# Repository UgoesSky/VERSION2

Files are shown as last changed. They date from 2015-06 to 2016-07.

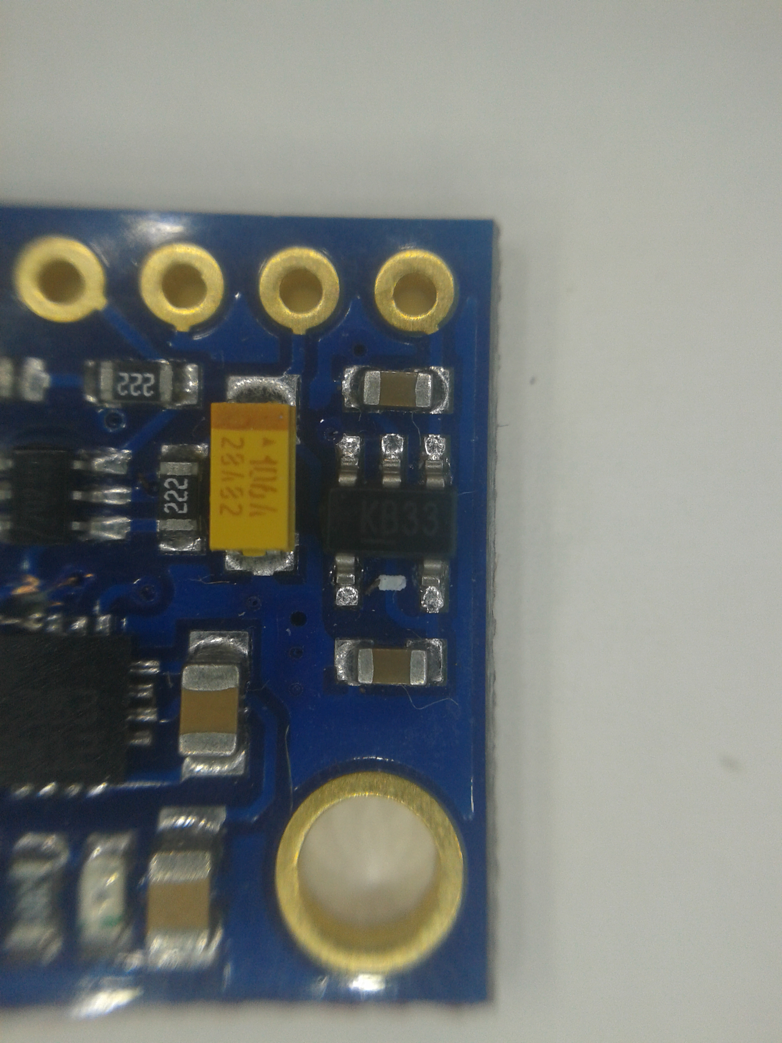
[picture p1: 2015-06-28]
Hardware/GY80/GY88_top1.jpg

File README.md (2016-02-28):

# What we are doing here?
We develop an balloon for the Stratosphere. We are a small group of students from a bording school in southern Germany, near Ulm. In 2014 we had the idea to develop and launch an balloon into the Stratosphere. Our first balloon launched on 20 March 2015 during the partial solar eclipse in Europe. At almost 22 km, our balloon, filled with helium, burst. The capsule landed save, hanging on a parachute.

Now we are developing our second balloon. We target this launch in Summer 2016.
# VERSION2
Die Daten für V2 des Ballonprojekts 'UgoesSky'.

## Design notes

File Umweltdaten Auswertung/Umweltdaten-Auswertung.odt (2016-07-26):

UgoesSky V2

Umweltdaten Auswertung

# Dateien

aprs_roh_v2.txt | APRS Rohdaten von aprs.fi
aprs.txt | APRS Daten unvollstäbdige Datensätze entfernt
aprs-zeit.txt | APRS Zeitstempel cat aprs.txt |grep -o 2016-07-17......... > aprs-zeit.txt
aprs-hoehe.txt | APRS Höhe in Fuß cat aprs.txt |grep -o A=...... > aprs-hoehe.txt
Umweltdaten.txt | Rohdaten Umwelt
Umweltdaten-Tabelle.ods | Tabelle und Diagramme

## Umweltdaten.ods

### Rohdaten

A | Zeit (MESZ) | Zeitstempel (kann etwas abweichen)
B | Temperatur Innen BMP085 (in °C) | Innentemperatur BMP085 | Genauigkeit: typ. ±1,0°C Auflösung: 0,1°C
C | Temperatur Außen seitlich DHT22 (in °C) | Außentemperatur seitlich DHT22 | Genauigkeit: typ. ±0,5°C Auflösung: 0,1°C
D | Temperatur Innen TMP75 (in °C) | Innentemperatur TMP75 | Genauigkeit: typ. ±0,5°C Auflösung: 0,0625°C
E | Temperatur Außen Unten TMP75 (in °C) | Außentemperatur unten TMP75
F | Temperatur Außen Oben TMP75 (in °C) | Außentemperatur oben TMP75 | Genauigkeit: typ. ±1,0°C Auflösung: 0,0625°C
G | Temperatur Innen TMP75 (in °C) roh | Rohwerte negative Werte falsch | =WENN(G3>100;G3-256;G3)
H | Temperatur Außen Unten TMP75 (in °C) roh
I | Temperatur Außen Oben TMP75 (in °C) roh
J | Absolute Luftfeuchte (in g/kg) | Berechnet aus relativer Luftfeuchte, Temperatur und Druck | =0,622*K3/100*L3/(M3-K3/100*L3)*1000
K | Relative Luftfeuchte (in %) | Relative Luftfeuchte seitlich DHT22 | Genauigkeit: typ. ±2% Auflösung: 0,1%
L | Wasserdampfpartialdurck (in Pa) | Nötig für Berechnung der absoluten Luftfeuchte | =WENN(C3<=0;4,689*(1,486+C3/100)^12,3;WENN(C3>0;288,68*(1,098+C3/100)^8,02;""))
M | Druck (in Pa) | Druck innen BMP085 | Genauigkeit: ±400Pa Auflösung: 1Pa
N | Standardatmosphäre | Druck / 101325 | Auflösung: 0,0001
O | Höhe (in m) | Aus Druck berechnete Höhe | Auflösung: 0,01m
P | Spannung (ADC-Wert) | Rohwert zwischen 0...1023 | ausgefallen
Q | Zähler | Zählervaiabler, Bereich 1...60 Bei Überlauf wird gespeichert

### APRS Höhe

A | Zeit (MESZ)
B | APRS Höhe (Meter) | =C2*0,3048
C | APRS Höhe (Fuß)

### Rohdiagramm

Diagramm mit allen Werten zum kopieren

### Temperatur

Temperaturkurven

### Temperatur Höhe

Temperaturkurven mit Höhe

### Höhe – APRS Höhe

Vergleich zwischen den Werten. Leichter Zeitoffset möglich.

### Druck Höhe

### Temperatur Luftfeuchte

Temperatur und Luftfeuchte

### Höhe Luftfeuchte

Höhe und Luftfeuchte

### Spannung Höhe

### Spannung Temperatur

# Interpretation

## Temperatur

Vor dem Start steigt die Außentemperatur oben durch Sonnenstrahlung an. Die Außentemperatur seitlich steigt nur leicht und die Außentemperatur unten wird nicht beeinflusst.

Am Anfang erwärmt sich die Box innen, die Wärme wird aber wieder nach außen abgegeben.

Ab etwa 12 km Höhe ist der Luftdruck zu gering, dass kaum mehr Wärme nach außen abgegeben werden kann (Vakuumisolation). Deshalb steigt die Außentemperatur am Styropor stark an. Nach einiger Zeit fängt auch die Innentemperatur an zu steigen.

Die Unterschiede zwischen den einzelnen Sensoren lassen sich durch die Erwärmung des Styropors und der Sonneneinstrahlung erklären. Die Erwärmung des Styropos ist von der Dicke und der Wärmeverteilung in der Box abhängig.

Der untere Sensor wird durch die Styroporschicht von 3cm und das direkt an das Styropor gekoppelte Funkgerät am stärkstem erwärmt.

Der obere Sensor wird vermutlich hauptsächlich durch Sonneneinstrahlung erwärmt, da hier das Styropor 6cm dick ist.

Der seitliche Sensor wird am wenigsten erwärmt, da hier weder eine Wärmequelle im Innern sitzt, noch die Sonneneinstrahlung so stark ist. Zudem ist der Sensor im Gegensatz zu den anderen Weiß statt schwarz.

## Luftfeuchte

In der relativen Luftfechte ist gut zu erkennen, dass der Ballon bei etwa 2,5 km die Wolken durchfliegt.

Außerdem gibt es noch Schwankungen zwischen 4km und 8km für die sich noch keine Erklärung gefunden hat.

Bis 16km sinkt die relative Luftfeuchte, bis sie bei 16km den Minimalwert erreicht hat.

## Ausfall

Das System ist um etwa 16:25 nach 1:40h Flugzeit und einer Laufzeit von gut 2h ausgefallen.

Es fallen keine Auffälligkeiten in den gemessene Werten auf. Nur die Akkuspannung wurde ab dem Start nicht mehr korrekt gemessen.

Weshalb das System ausgefallen ist, ist noch nicht geklärt.

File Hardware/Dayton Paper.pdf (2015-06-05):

## Proposal for SSTV Mode Specifications

JL Barber (N7CXI), Silicon Pixels Presented at the Dayton SSTV forum, 20 May 2000

Forward
When I first began investigating the requirements for designing an SSTV system, one of the first obstacles I ran into was the lack of accurate information on the exact format and timings of the many SSTV modes in use. All the information I found was either generalized, or based on the results of reverse engineering existing systems. As so often noted, this has resulted in many compatibility problems over the years. This paper is a beginning at changing that. The reason I call it a beginning is that other developers may not agree that the specifications presented here should become standards. Even so, every venture must start somewhere. If the developer’s community at large can agree on reasonable standards, we’ll be happy to adopt them. In the meantime, we present these proposed specifications for use or publication by anyone who finds them useful.

Data sources
The specifications presented in this paper include only those that we have “hard” data for. In the case of Scottie, Martin, Robot, and Wrasse modes, our source is the firmware for the Robot 1200C. For other modes:
Pasokon “P” modes | John Langner | (author)
“PD” modes | Don Rotier | (author)
FAX480 | Dr. Ralph Taggart (author)
Note: | Those familiar with our ChromaPIX and W95SSTV systems will note the absence of specifications for the AVT
modes. Since we have no solid data on AVT from the author, we have not included them here.
Numeric precision
The timings specified here are generally given in milliseconds, (ms) except where other units work better for examples. Scan times have been rounded to .001ms, which is adequate precision for any known application. Total transmission times are not calculated precisely, since the exact lengths aren’t relevant for development purposes. In the case of the Robot firmware, we can provide the 8031 clock frequency and “counts”, if absolute precision is desired.

Disclaimer
While every attempt has been made to ensure the accuracy of this information, we can’t absolutely guarantee it to be completely without error.

Layout
Rather than present mode timings with pictures, we’ve chosen to “step through” each mode, in sequence. We believe this method will be more useful to developers, as it reveals the sequence of events more readily than an image.

VIS Code and Robot calibration header
All standard SSTV modes utilize a unique digital code that identifies the mode to a receiving system. The code is called the VIS, or Vertical Interval Signal code. Although the entire calibration header is often referred to as the “VIS code”, the code itself is only a part of it. The seven-bit code is transmitted least-significant-bit (LSB) first, and uses “even” parity.

Calibration header with VIS code

TIME(ms) | FREQUENCY(hz) | IDENTITY
300 | 1900 | Leader tone
10 | 1200 | break
300 | 1900 | Leader tone
30 | 1200 | VIS start bit
30 | bit 0 | 1100hz = “1”, 1300hz = “0”
30 | bit 1 | “”
30 | bit 2 | “”
30 | bit 3 | “”
30 | bit 4 | “”
30 | bit 5 | “”
30 | bit 6 | “”
30 | PARITY | Even=1300hz, Odd=1100hz
30 | 1200 | VIS stop bit

Note that all mode specifications begin immediately after the VIS stop bit.

SCOTTIE MODES
“Scottie” modes, although the most commonly used modes in the US, are unusual for two reasons. The combination of the two has caused considerable confusion over the years:
- The first scan line (only) begins with an out-of-sequence 9.0ms “starting” sync pulse, at 1200hz.
- The “regular” sync pulse is positioned between the Blue and Red scans, rather than at the line break, as with other modes.

VIS CODES
Scottie 1 | 60d (decimal)
Scottie 2 | 56d
Scottie DX 76d
COLOR MODE | RGB (1500-2300hz luminance range)
SCAN SEQUENCE | Green, Blue, Red
NUMBER OF LINES | 256
NORMAL DISPLAY RES 320x256 (including 16-line header)

TRANSMISSION TIME
Scottie 1 | 109.6 seconds (not including cal. header/VIS)
Scottie 2 | 71.1 seconds
Scottie DX | 268.9 seconds

COLOR SCAN TIME
Scottie 1 | 138.240ms (.4320ms/pixel @ 320 pixels/line)
Scottie 2 | 88.064ms (.2752ms/pixel @ 320 pixels/line)
Scottie DX 345.6ms | (1.0800ms/pixel @ 320 pixels/line)

TIMING SEQUENCE
(1) “Starting” sync pulse (first line only!) | 9.0ms | 1200hz
(2) Separator pulse | 1.5ms | 1500hz
(3) Green scan
(4) Separator pulse | 1.5ms | 1500hz
(5) Blue scan
(6) Sync pulse | 9.0ms | 1200hz
(7) Sync porch | 1.5ms | 1500hz
(8) Red scan

After the first line, repeat steps 2 – 8 for all following lines.

MARTIN MODES
Martin modes are straightforward, with the sync pulse occurring at line breaks.

VIS CODES
Martin 1 | 44d (decimal)
Martin 2 | 40d
COLOR MODE | RGB (1500-2300hz luminance range)
SCAN SEQUENCE | Green, Blue, Red
NUMBER OF LINES | 256
NORMAL DISPLAY RES 320x256 (including 16-line header)

TRANSMISSION TIME
Martin 1 | 114.3 seconds (not including cal. header/VIS)
Martin 2 | 58.06 seconds

COLOR SCAN TIME
Martin 1 | 146.432ms (.4576ms/pixel @ 320 pixels/line)
Martin 2 | 73.216ms (.2288ms/pixel @ 320 pixels/line)

TIMING SEQUENCE
(1) Sync pulse | 4.862ms | 1200hz
(2) Sync porch | 0.572ms | 1500hz
(3) Green scan
(4) Separator pulse | 0.572ms | 1500hz
(5) Blue scan
(6) Separator pulse | 0.572ms | 1500hz
(7) Red scan
(8) Separator pulse | 0.572ms | 1500hz

Repeat the above sequence for 256 lines.

ROBOT 36 COLOR
Robot 36 is probably the most complex of all SSTV modes:
- It uses Y, R-Y, B-Y color encoding
- The R-Y color information is averaged for two lines, and transmitted on even lines.
- The B-Y color information is averaged for two lines, and transmitted on odd lines.
- The R-Y and B-Y scans have only ½ the period (44ms) of the Y scan. (88ms)
- Even lines use a 1500hz “separator” pulse, while odd lines use 2300hz.

VIS CODE 8d (decimal)

COLOR MODE | Y, R-Y, B-Y (see Appendix B)
SCAN SEQUENCE | Y, R-Y (even lines) Y, B-Y (odd lines)
NUMBER OF LINES | 240
TRANSMISSION TIME | 36 seconds (not including cal. header/VIS)

Note: For clarity, 2 complete lines are shown below

TIMING SEQUENCE
(1) Sync pulse | 9.0ms | 1200hz
(2) Sync porch | 3.0ms | 1500hz
(3) Y scan | 88.0ms
(4) “Even” separator pulse | 4.5ms | 1500hz
(5) Porch | 1.5ms | 1900hz
(6) R-Y scan | 44ms
(7) Sync pulse | 9.0ms | 1200hz
(8) Sync porch | 3.0ms | 1500hz
(9) Y scan | 88.0ms
(10) “Odd” separator pulse | 4.5ms | 2300hz
(11) Porch | 1.5ms | 1900hz
(12) B-Y scan | 44ms

Repeat the sequence above for 240 lines.

ROBOT 72 COLOR
Robot 72 is somewhat simpler than Robot 36, but still suffers from different scan periods for the Y versus the R-Y and B-Y scans.

VIS CODE 12d (decimal)

COLOR MODE | Y, R-Y, B-Y (see Appendix B)
SCAN SEQUENCE | Y, R-Y, B-Y
NUMBER OF LINES | 240
TRANSMISSION TIME | 72 seconds (not including cal. header/VIS)
TIMING SEQUENCE | (one line shown)
(1) Sync pulse | 9.0ms | 1200hz
(2) Sync porch | 3.0ms | 1500hz
(3) Y scan | 138ms
(4) Separator pulse | 4.5ms | 1500hz
(5) Porch | 1.5ms | 1900hz
(6) R-Y scan | 69ms
(7) Separator pulse | 4.5ms | 2300hz
(8) Porch | 1.5ms | 1500hz
(9) B-Y scan | 69ms

Repeat the above sequence for 240 lines.

WRASSE SC2-180
SC2-180 is probably the simplest RGB SSTV mode.

VIS CODE 55d (decimal)

COLOR MODE | RGB (1500-2300hz luminance range)
SCAN SEQUENCE | Red, Green, Blue
NUMBER OF LINES | 256
TRANSMISSION TIME | 182 seconds (not including cal. header/VIS)
COLOR SCAN TIME | 235.000ms (.7344ms/pixel @ 320 pixels/line)
TIMING SEQUENCE | (one line shown)
(1) Sync pulse | 5.5225ms | 1200hz
(2) Porch | 0.500ms | 1500hz
(3) Red scan
(4) Green scan
(5) Blue scan

Repeat the above sequence for 256 lines.

PASOKON “P” modes
The “P” modes are all designed to display at 640x496, including a 16-line header. They differ somewhat from other “families” of modes, in that the sync pulse and porch periods vary with the sub-mode. When John Langner originally authored them, his intent was that the pixel clock, sync, and porch periods all be evenly divisible into a standard RS232 clock rate.

VIS CODES:
P3 | 113d (decimal)
P5 | 114d
P7 | 115d
COLOR MODE | RGB (1500-2300hz luminance range)
SCAN SEQUENCE | Red, Green, Blue
NUMBER OF LINES | 496

TRANSMISSION TIMES
P3 | 203 seconds (not including cal. header/VIS)
P5 | 304.6 seconds
P7 | 406.1 seconds

COLOR SCAN TIMES:
P3 | 133.333ms (.2083ms/pixel @ 640 pixels/line)
P5 | 200.000ms (.3125ms/pixel @ 640 pixels/line)
P7 | 266.666ms (.4167ms/pixel @ 640 pixels/line)

SYNC PERIODS
P3 | 5.208ms | 1200hz
P5 | 7.813ms | 1200hz
P7 | 10.417ms | 1200hz

PORCH PERIODS
P3 | 1.042ms | 1500hz
P5 | 1.563ms | 1500hz
P7 | 2.083ms | 1500hz
TIMING SEQUENCE | (one line shown)
(1) Sync pulse
(2) Porch
(3) Red scan
(4) Porch
(5) Green scan
(6) Porch
(7) Blue scan
(8) Porch
| Repeat the above sequence for 496 lines.

PD Modes
The PD modes were developed jointly by Don Rotier and Paul Turner. Although they’re a little complicated, they represent a fair trade-off between color accuracy and transmission time.

VIS CODES
PD50 | 93d (decimal)
PD90 | 99d
PD120 | 95d
PD160 | 98d
PD180 | 96d
PD240 | 97d
PD290 | 94d
COLOR MODE | Y, R-Y, B-Y (See Appendix B)
SCAN SEQUENCE | Y, R-Y, B-Y

NORMAL DISPLAY RESOLUTION
PD50 | 320x256 | (all include 16-line header)
PD90 | 320x256
PD120 | 640x496
PD160 | 512x400
PD180 | 640x496
PD240 | 640x496
PD290 | 800x616

TRANSMISSION TIMES
PD50 | | 49.7 seconds
PD90 | | 90.0 seconds
PD120 | | 126.1 seconds
PD160 | | 160.9 seconds
PD180 | | 187.1 seconds
PD240 | | 248.0 seconds
PD290 | | 288.7 seconds

COLOR SCAN TIMES (Y, R-Y, B-Y)
PD50 | | 91.520ms
PD90 | | 170.240ms
PD120 | | 121.600ms
PD160 | | 195.584ms
PD180 | | 183.040ms
PD240 | | 244.480ms
PD290 | | 228.800ms

TIMING SEQUENCE
Note: two complete lines are shown.
(1) Sync pulse | 20.000 | 1200hz
(2) Porch | 2.080ms | 1500hz
(3) Y scan (from odd line)
(4) R-Y scan averaged for two lines
(5) B-Y averaged for two lines
(6) Y scan (from even line)

Repeat until correct number of lines are transmitted for sub-mode.

FAX480 mode

FAX480 is a monochrome FAX, rather than a “true” SSTV mode. It uses a 5-second FAX tone “header” followed by a phasing area, instead of a Robot calibration header and VIS code. It was developed by Dr. Ralph Taggart, WB8DQT

We’ve included it here because it’s useful for monochrome image transmission, and is often included with SSTV software. (ChromaPIX included)

COLOR MODE | Monochrome (1500-2300hz luminance range)
NORMAL DISPLAY RES 512x480
NUMBER OF LINES | 480
SCAN TIME | .512ms x 512 pixels = 262.144ms

HEADER (start tone)
(1) | 2.05ms | 2300hz
(2) | 2.05ms | 1500hz

Repeat this sequence 1220 times, for a total of 5.002 seconds.

PHASING INTERVAL (20 lines)
(1) | Sync | 5.12ms | 1200hz
(2) | White | .512ms x 512 pixels = 262.144ms

Repeat this sequence 20 times, for a total of 20 lines.

TIMING SEQUENCE
(1) Header
(2) Phasing interval
(3) Sync | | 5.12ms | 1200hz
(4) Scan line

Repeat 3-4 until 480 lines have been transmitted.

Note: Some systems (ChromaPIX included) use the 20-line phasing area for video.)

Appendix A | RGB Color Encoding

Of the two encoding methods used in SSTV, RGB is by far the simplest. The calculations below are intended for use with non-linear 24-bit RGB color, which is standard for modern computer-based systems.

24-bit RGB is straightforward. 8-bit (0-255) Red, Green, and Blue values are “packed” into a single 24-bit identity. Red values occupy the lowest 8 bits, followed by Green, then Blue. This allows for a maximum of 16,777,216 unique combinations of colors, which is generally adequate for any but the highest-end imaging systems.

To extract individual 8-bit R,G,B values from a 24-bit RGB encoded pixel :

RedByte | = colorval AND 255
GreenByte | = (colorval AND 65280) / 256
BlueByte | = (colorval AND 16711680) / 65536

If your programming language and platform supports it, shifting and masking the 24-bit value may be slightly faster than using the “generic” method above, since it would avoid the division.

SSTV systems use the frequency range of 1500-2300hz to represent the range of brightness values from pure black to pure white. Because of this, we must convert our 8-bit R,G,B values into the appropriate frequency:

Frequency = 1500 + (ColorByte * 3.1372549)

Conversely, to derive the 8-bit R,G, or B value from a frequency:

ColorByte = (Frequency – 1500 ) / 3.1372549

Obviously, look-up tables could be calculated in advance, avoiding the necessity of performing floating-point multiplies and divisions for encoding and decoding every pixel in every scan.

For receiving purposes, the easiest way to recombine the individual R,G, and B values back into a 24-bit RGB identity is to use the RGB(n,n,n) macro provided with most modern compilers. If that isn’t possible :

RedVal | = ColorByte (directly, no conversion required)
GreenVal | = ColorByte * 256
BlueVal | = ColorByte * 65536

Once the R, G, and B values have been scaled correctly, they can be simply added together to form the 24-bit identity:

ColorVal = Red + Green + Blue

Appendix B | Y, R-Y, B-Y Color Encoding

(Y, R-Y, B-Y) encoding is used in Robot and PD modes, as well as the seldom-used Wrasse SC2-120 mode. This method of encoding is also referred to as (Y/C), (Y’U’V’), (Y’CBCR), and other names. Although all these refer to the same overall method of encoding, the exact scalings used vary somewhat by implementation and developer.

The encoding used in ChromaPIX and W95SSTV is compliant with
ITU BT. Rec. 601. (the 1953 NTSC standard) Because there has been no clearly-defined standard, the scalings described below may vary slightly from those used by other developers.

To convert non-linear RGB to [Y, R-Y, B-Y] (scaled 0-255) :

Y = 16.0 + (.003906 * ((65.738 * R) + (129.057 * G) + (25.064 * B)))

RY = 128.0 + (.003906 * ((112.439 * R) + (-94.154 * G) + (-18.285 * B)))

BY = 128.0 + (.003906 * ((-37.945 * R) + (-74.494 * G) + (112.439 * B)))

Again, as with RGB encoding, these values can be converted to frequency, for SSTV transmission :

Frequency = 1500 + (v * 3.1372549)
(where ‘v’ is the Y, R-Y, or B-Y value)

Conversely, Y, R-Y, B-Y values scaled 0-255 may be converted back to non-linear RGB:

R = 0.003906 * ((298.082 * (Y – 16.0)) + (408.583 * (RY – 128.0)))

G = 0.003906 * ((298.082 * (Y – 16.0)) + (-100.291 * (BY – 128.0)) + (-208.12 * (RY – 128.0)))

B = 0.003906 * ((298.082 * (Y – 16.0)) + (516.411 * (BY – 128.0)))

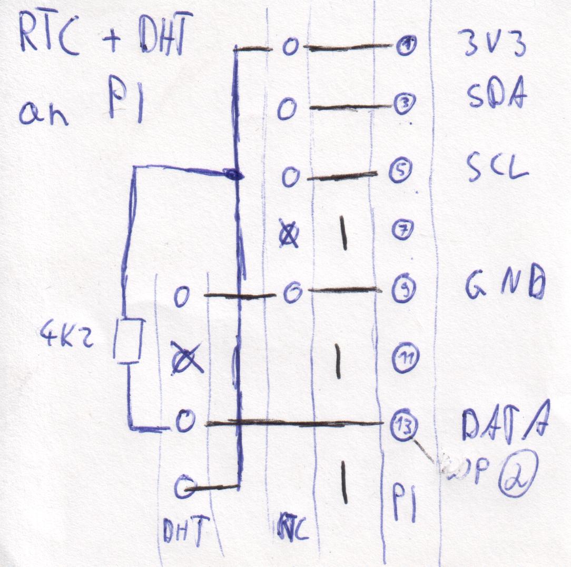
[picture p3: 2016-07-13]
Hardware/RTC-DHT-PI.jpg

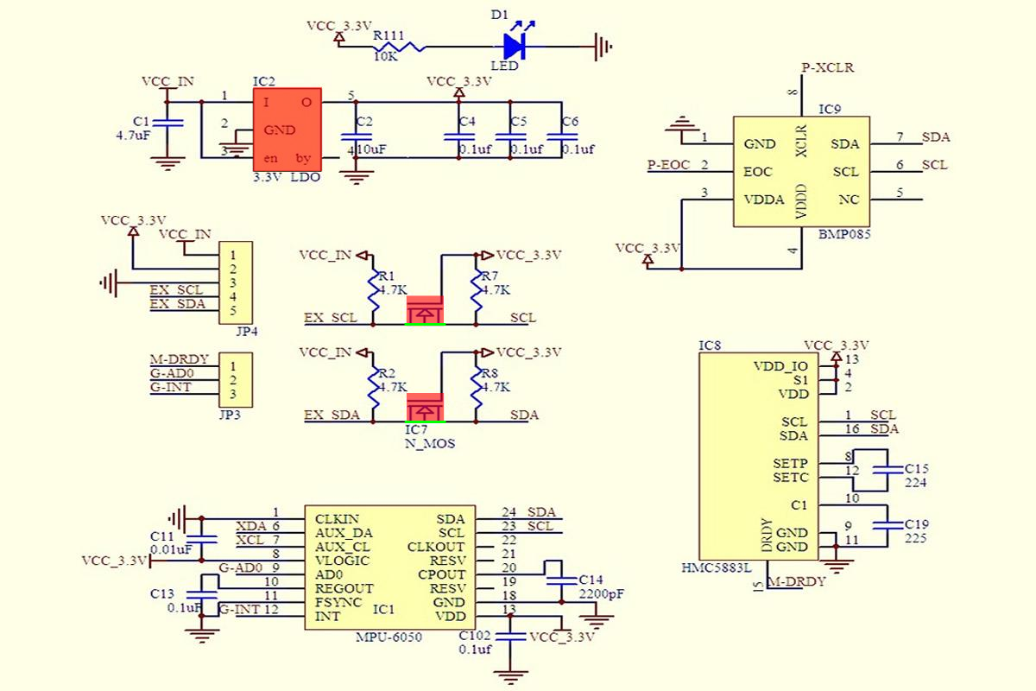
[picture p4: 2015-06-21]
Hardware/GY80/GY88_3.3v_SCHALTPLAN.png

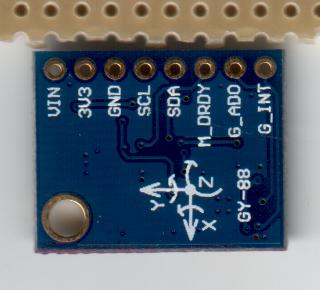
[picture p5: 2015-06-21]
Hardware/GY80/GY88_bottum.jpg

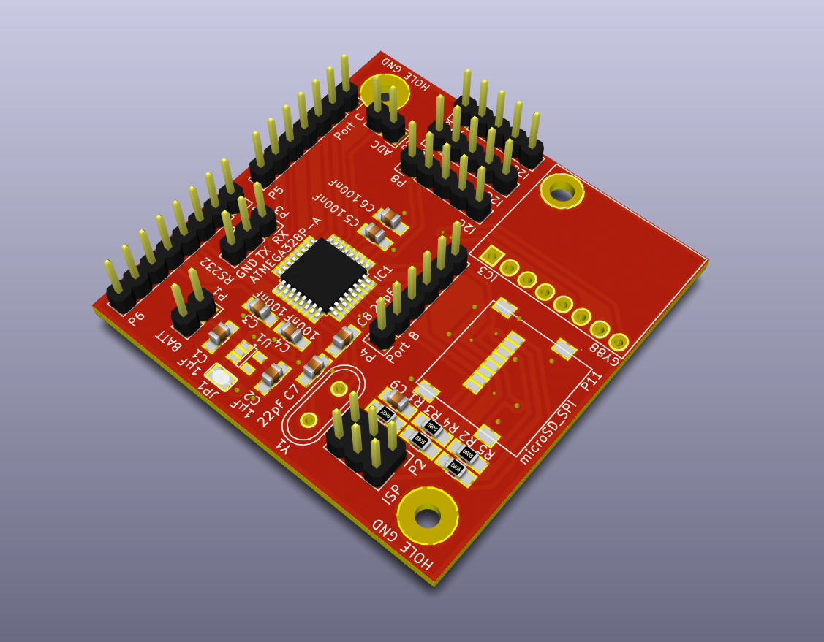
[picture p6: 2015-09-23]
Hardware/Umweltdaten/Bilder/top_3d.png

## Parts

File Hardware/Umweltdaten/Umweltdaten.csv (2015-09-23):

Reference | Value | Footprint | Datasheet
C1 | 1µF | Capacitors_SMD:C_0805_HandSoldering
P1 | BATT | Pin_Headers:Pin_Header_Straight_1x02
U1 | TLV70233DBV | Housings_SOT-23_SOT-143_TSOT-6:SOT-23-5
JP1 | Ureg EN | Footprints:SJ
C2 | 1µF | Capacitors_SMD:C_0805_HandSoldering
R5 | 10k | Resistors_SMD:R_0805_HandSoldering
R4 | 10k | Resistors_SMD:R_0805_HandSoldering
R3 | 10k | Resistors_SMD:R_0805_HandSoldering
R2 | 10k | Resistors_SMD:R_0805_HandSoldering
P11 | microSD_SPI | Footprints:microSD
IC3 | GY88 | Footprints:GY88
JP2 | G_AD0 | Footprints:SJ_2
IC1 | ATMEGA328P-A | Housings_QFP:TQFP-32_7x7mm_Pitch0.8mm
C4 | 100nF | Capacitors_SMD:C_0805_HandSoldering
C5 | 100nF | Capacitors_SMD:C_0805_HandSoldering
C3 | 100nF | Capacitors_SMD:C_0805_HandSoldering
Y1 | Crystal 16Mhz | Crystals:Crystal_HC49-U_Vertical
C7 | 22pF | Capacitors_SMD:C_0805_HandSoldering
C8 | 22pF | Capacitors_SMD:C_0805_HandSoldering
C9 | 100nF | Capacitors_SMD:C_0805_HandSoldering
R1 | 10k | Resistors_SMD:R_0805_HandSoldering
C6 | 100nF | Capacitors_SMD:C_0805_HandSoldering
P3 | RS232 | Pin_Headers:Pin_Header_Straight_1x03
P2 | ISP | Pin_Headers:Pin_Header_Straight_2x03
P5 | Port C | Pin_Headers:Pin_Header_Straight_1x07
P6 | Port D | Pin_Headers:Pin_Header_Straight_1x08
P7 | ADC | Pin_Headers:Pin_Header_Straight_1x02
P8 | I2C | Pin_Headers:Pin_Header_Straight_1x05
P9 | I2C | Pin_Headers:Pin_Header_Straight_1x05
P10 | I2C | Pin_Headers:Pin_Header_Straight_1x05
P4 | Port B | Pin_Headers:Pin_Header_Straight_1x06

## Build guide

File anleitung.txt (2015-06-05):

1. Dateien verändern
2. Im richtigen Branch?
	git checkout master
		     sstv
3. Veränderte Dateien in staging packen
entweder
	git add <DATEINAME> 	für einzelne Datei
oder
	git add .		für alle Veränderungen
3. Commit erstellen
	git commit -m "BESCHREIBUNG"
Nun befindet sich die aktuelle Version im lokalen Repository.
4. Änderung auf den Server schicken
	git push <origin BRANCHNAME>
wenn Fehlermeldung, Repo aktualisieren
	git pull <origin BRANCHNAME>
5. Weiter bei Schritt 1

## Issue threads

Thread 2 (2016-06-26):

Umweldaten Platine

jstjst, 2016-06-26:
- [ ] microSD card footprint wrong
- [ ] microSD card wrong oriantation
- [ ] Batt connector no polarity marking
- [ ] I2C pullups
- [ ] TMP75 O.S. not connected
- [ ] ISP connector no polarity makring
- [ ] TLV70233 NC pin
- [ ] GY88 G_AD0 pin connected to GND

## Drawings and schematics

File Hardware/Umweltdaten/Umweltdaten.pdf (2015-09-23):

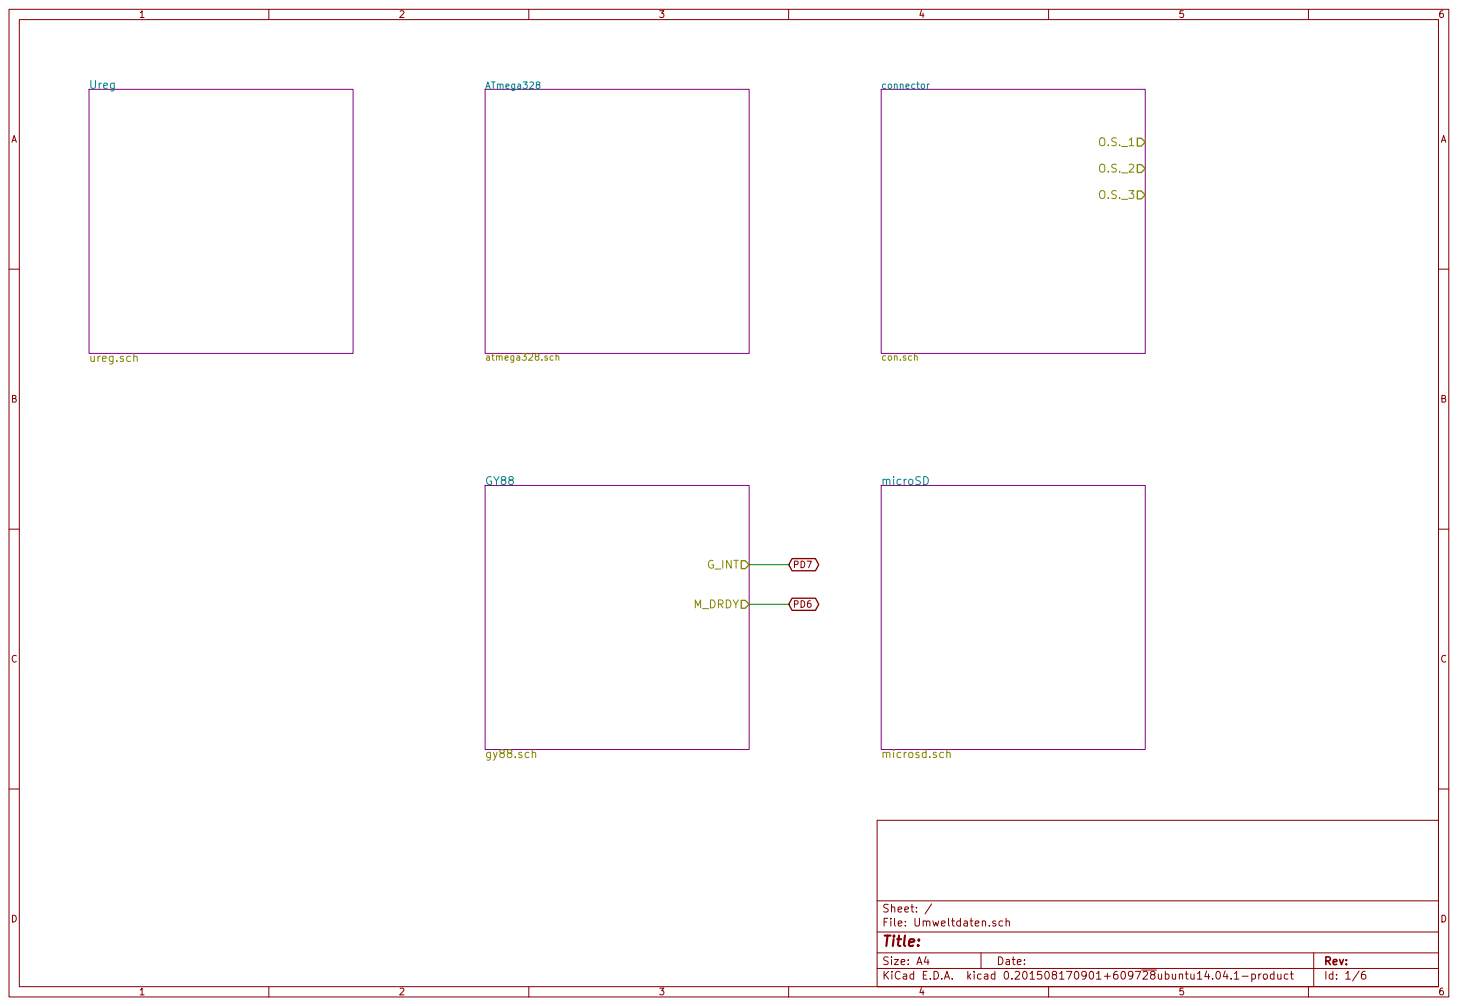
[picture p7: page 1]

Id: 1/6 Title: File: Umweltdaten.sch Sheet: /

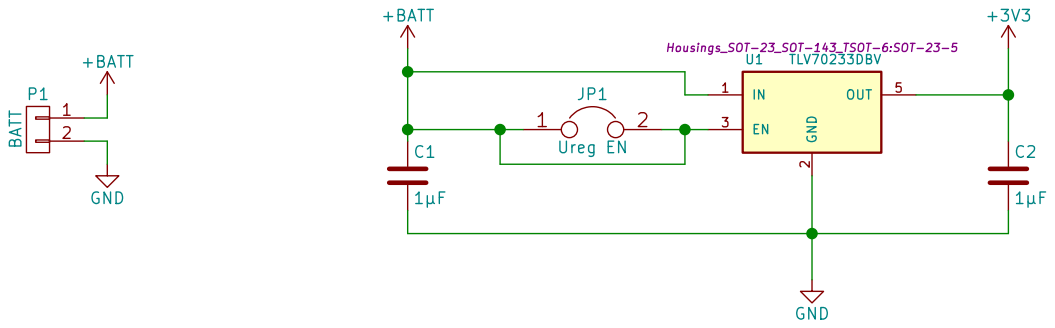
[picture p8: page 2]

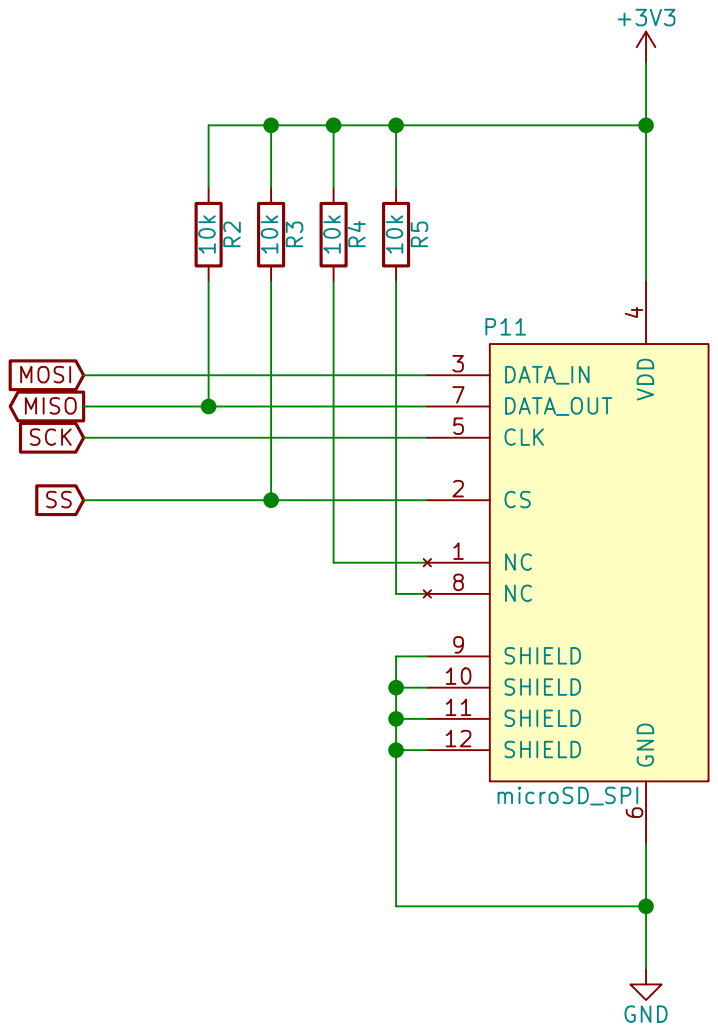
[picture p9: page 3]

6 DATA_OUT 7 NC 8 SHIELD 9 SHIELD 10 SHIELD 11 SHIELD 12 P11microSD_SPI

Id: 3/6 Title: File: microsd.sch Sheet: /microSD/

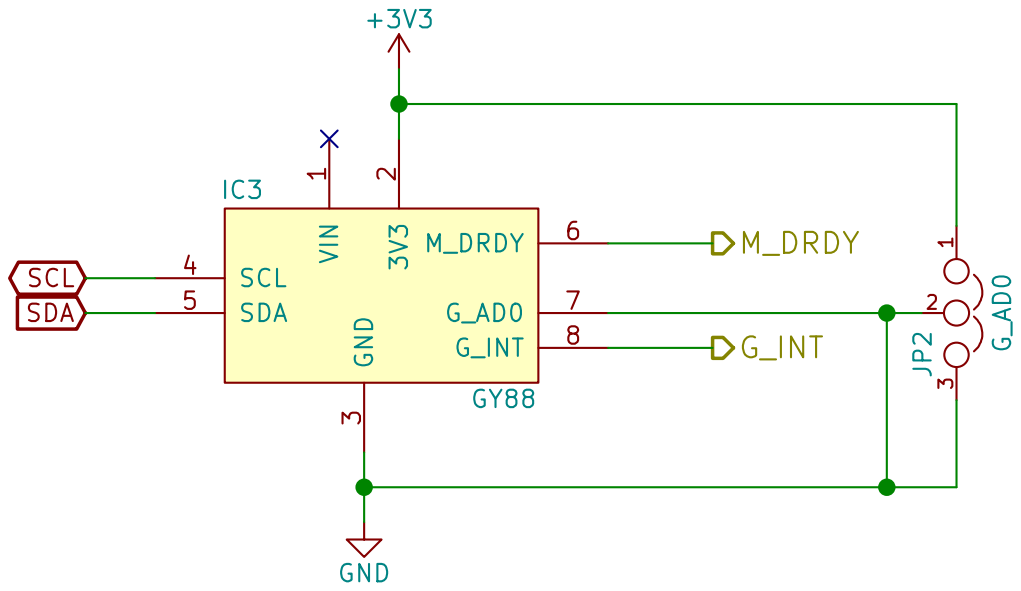
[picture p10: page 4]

File: gy88.sch Sheet: /GY88/ VIN

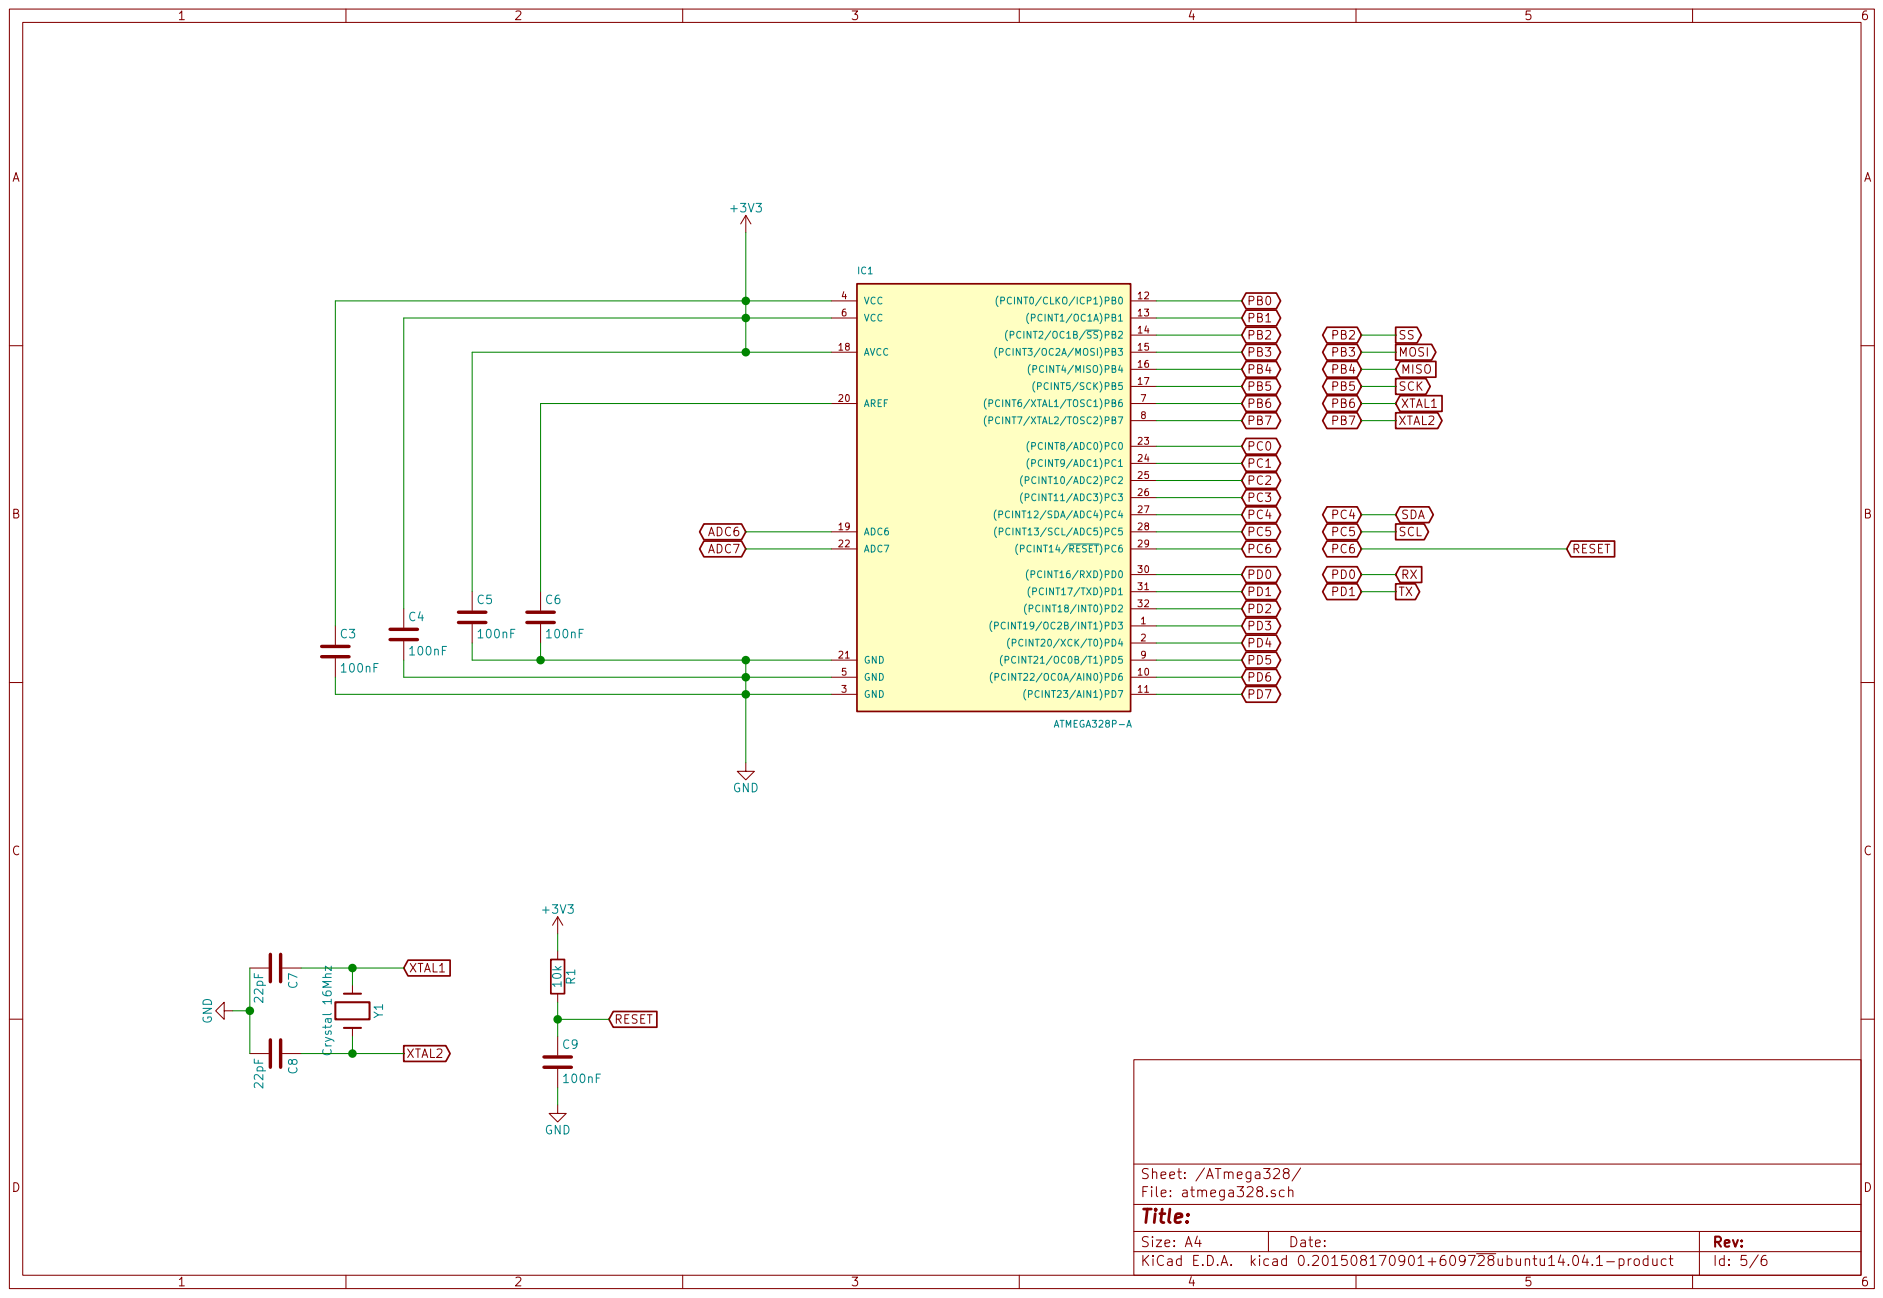
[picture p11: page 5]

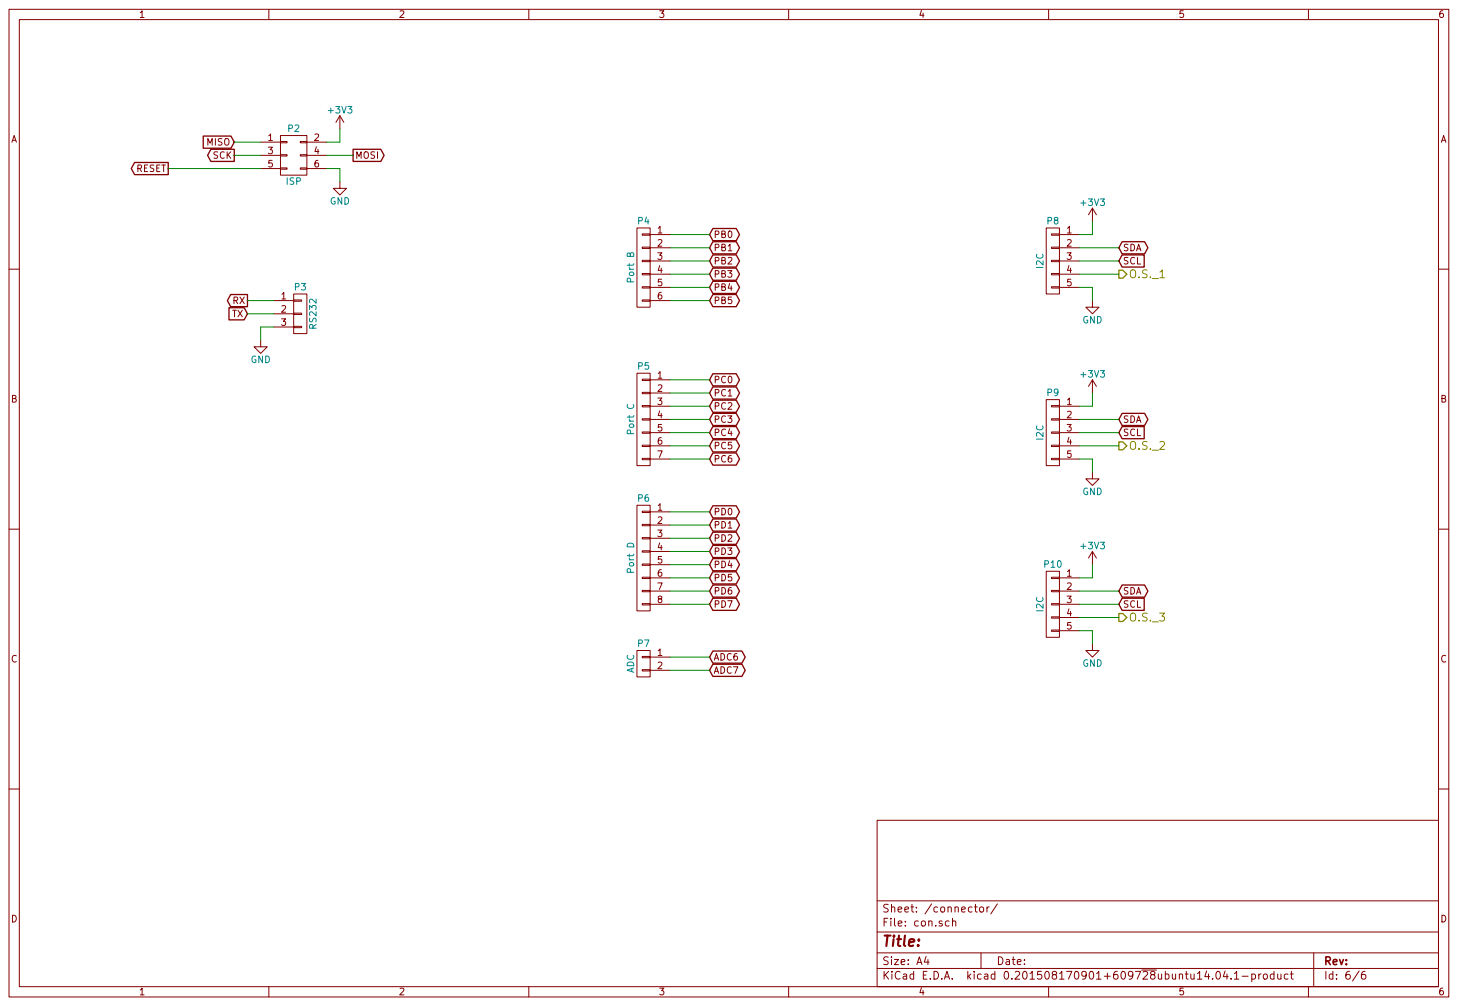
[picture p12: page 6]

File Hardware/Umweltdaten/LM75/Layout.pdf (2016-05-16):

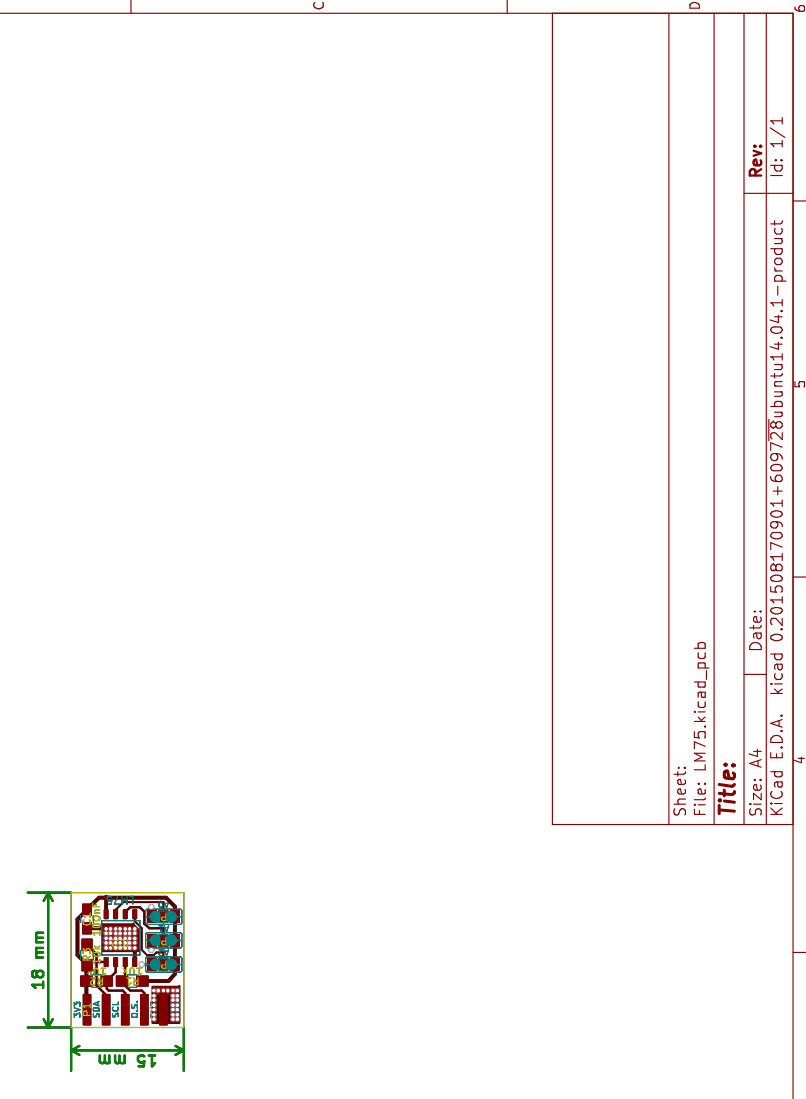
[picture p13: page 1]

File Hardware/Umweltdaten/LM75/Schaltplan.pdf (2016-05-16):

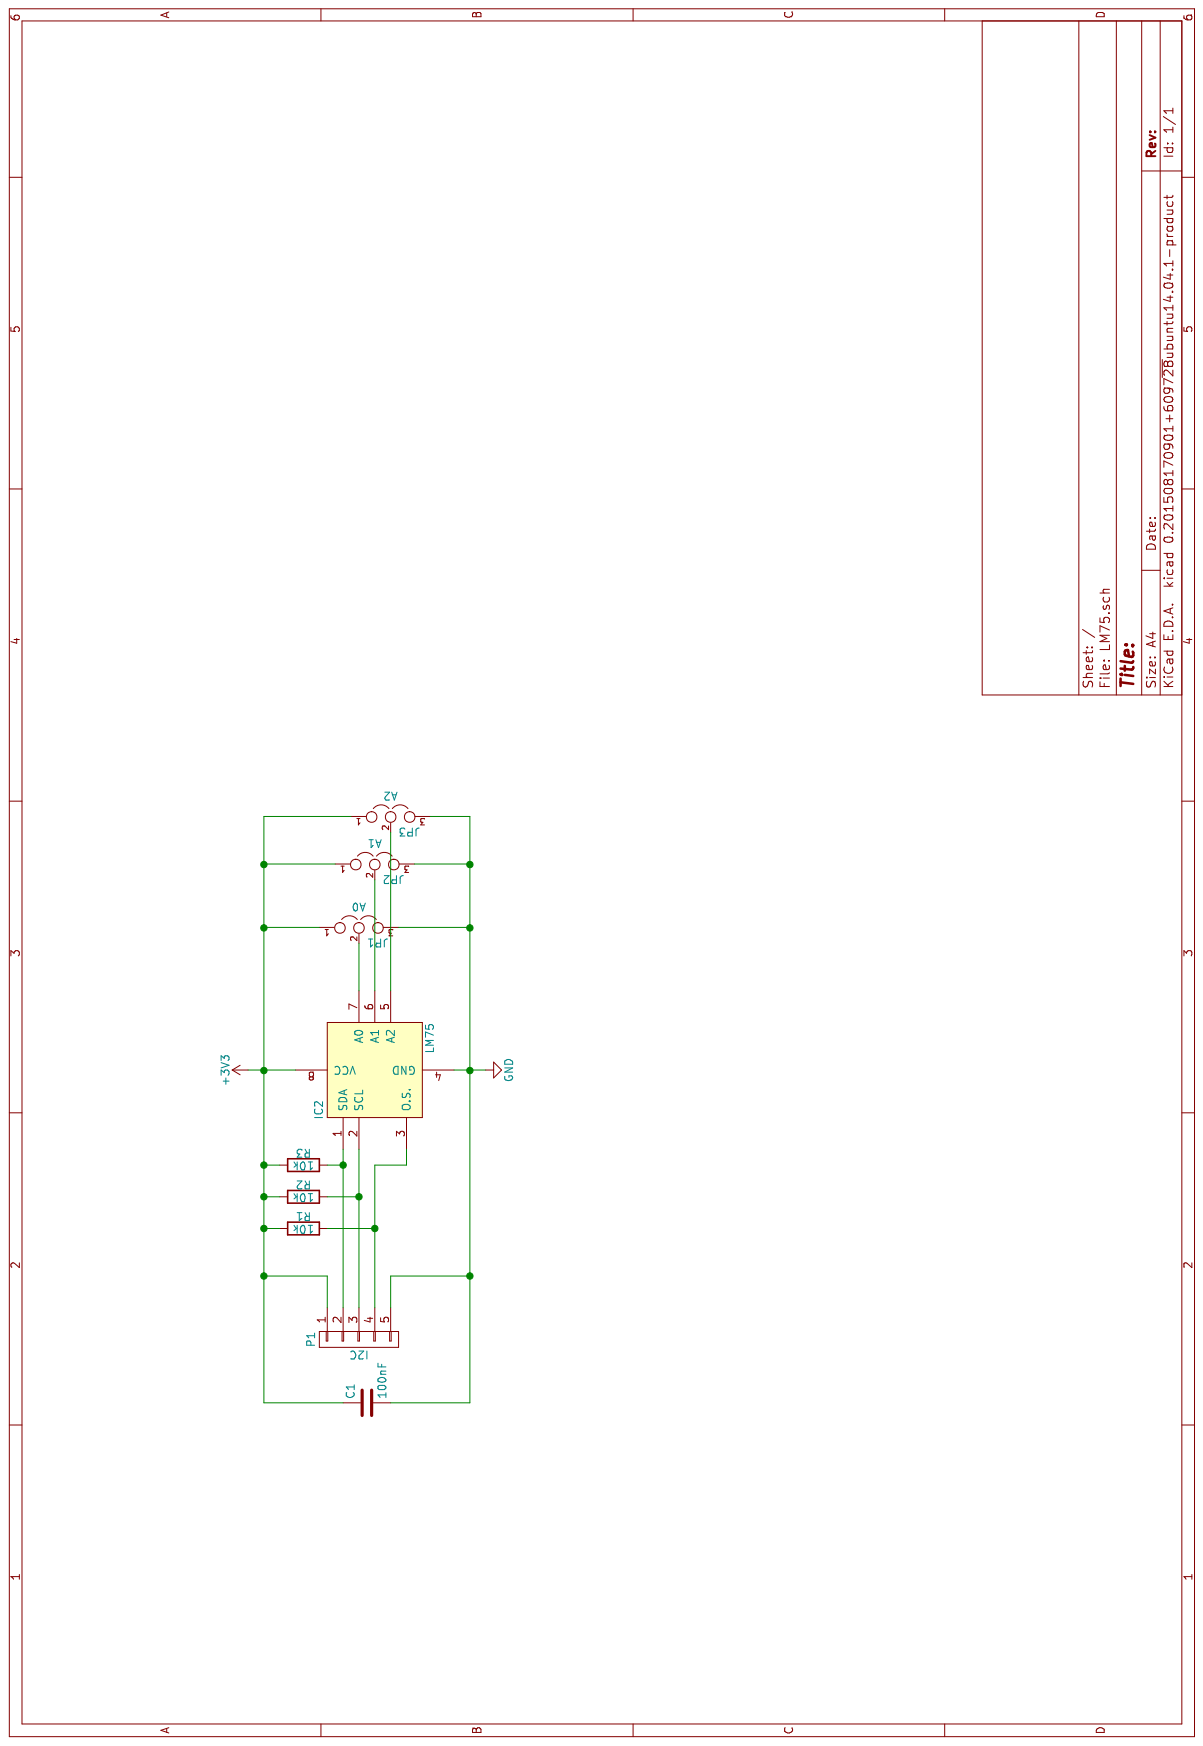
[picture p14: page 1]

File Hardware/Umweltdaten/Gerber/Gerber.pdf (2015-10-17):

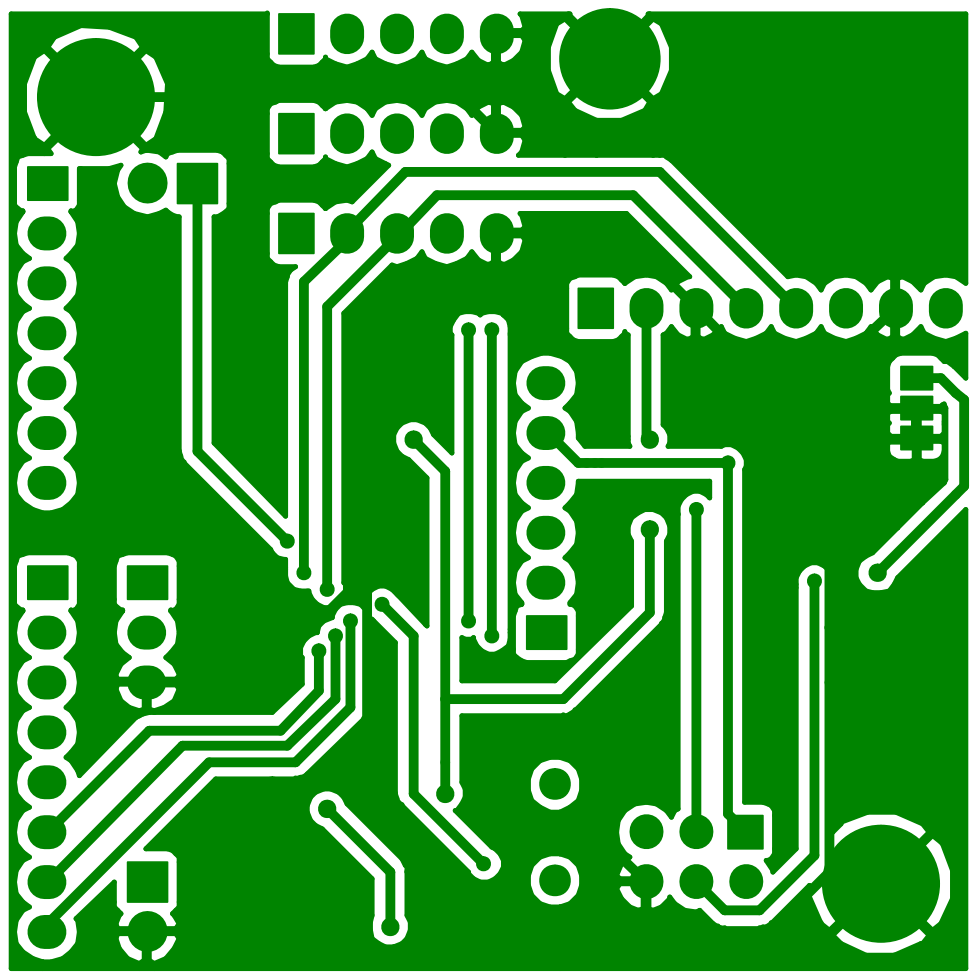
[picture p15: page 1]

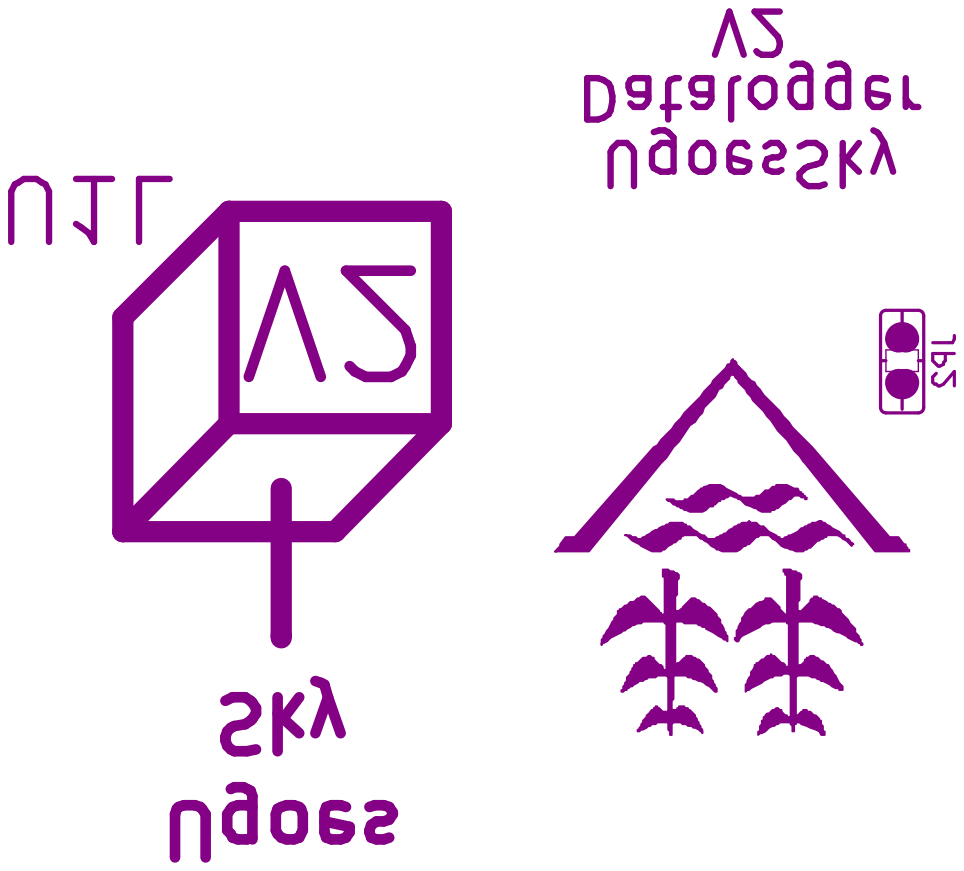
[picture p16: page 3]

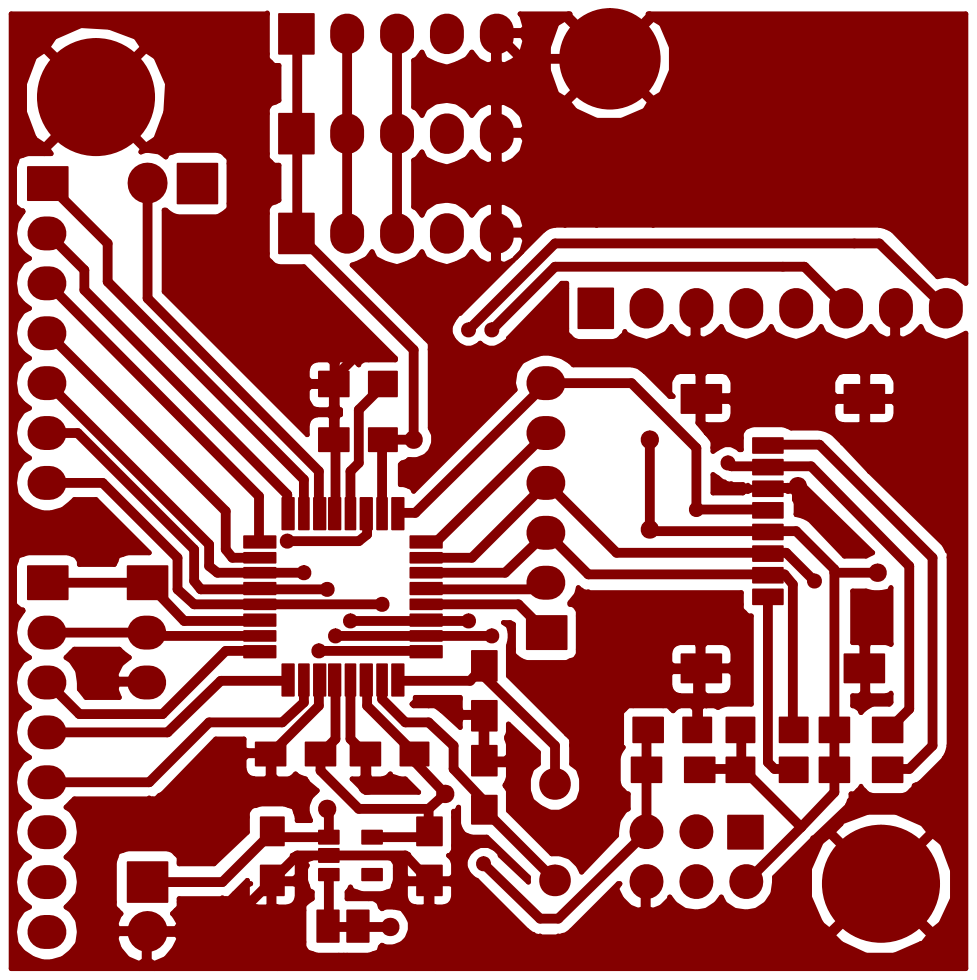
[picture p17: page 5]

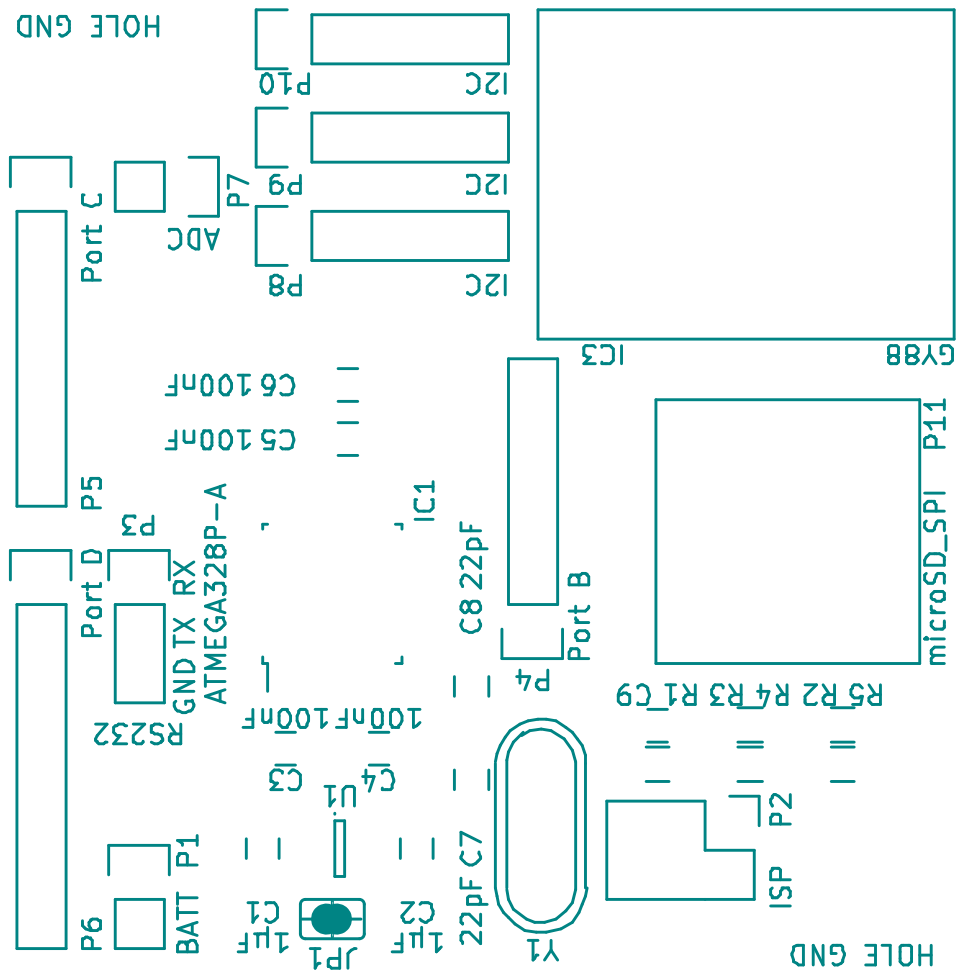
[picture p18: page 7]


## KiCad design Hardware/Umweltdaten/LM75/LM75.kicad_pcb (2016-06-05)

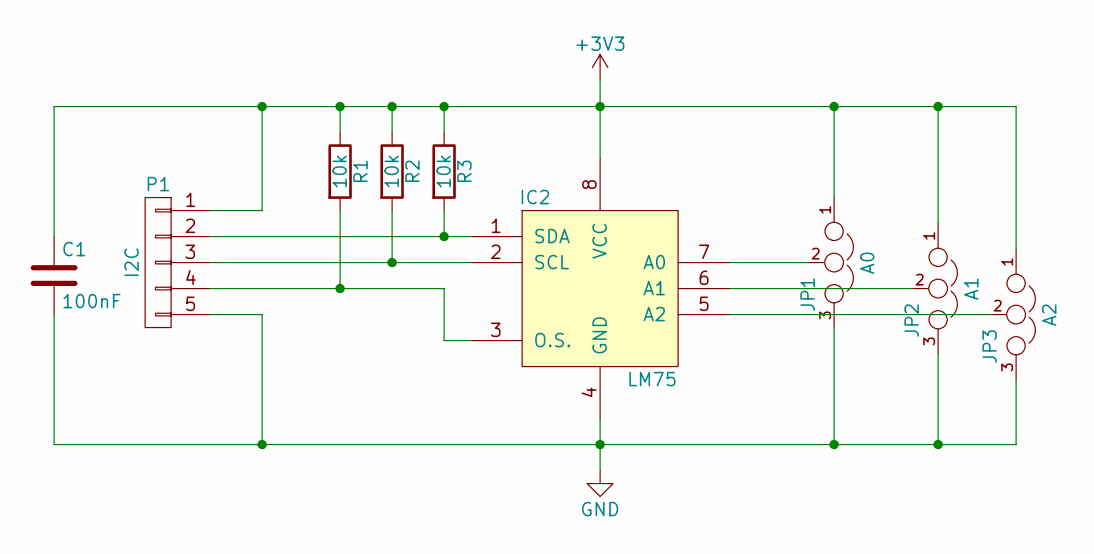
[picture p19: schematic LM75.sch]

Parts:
C1: 100nF; C_0805_HandSoldering
IC2: LM75; SOIC-8-N
JP1: A0; SJ_2
JP2: A1; SJ_2
JP3: A2; SJ_2
P1: I2C; SMD_05-4mm
R1, R2, R3: 10k; R_0805_HandSoldering

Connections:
+3V3: C1.1, IC2.8 (VCC), JP1.1, JP2.1, JP3.1, P1.1, R1.1, R2.1, R3.1
GND: C1.2, IC2.4 (GND), JP1.3, JP2.3, JP3.3, P1.5
unnamed: IC2.1 (SDA), P1.2, R3.2
unnamed: IC2.2 (SCL), P1.3, R2.2
unnamed: IC2.3 (O.S.), P1.4, R1.2
unnamed: IC2.5 (A2), JP3.2
unnamed: IC2.6 (A1), JP2.2
unnamed: IC2.7 (A0), JP1.2

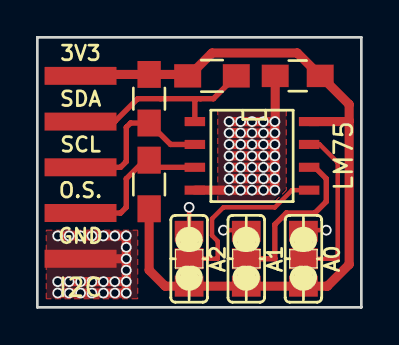
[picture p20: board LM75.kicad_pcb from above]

Board: 2 copper layers, 18.0 x 15.0 mm, 9 parts (0 on the bottom side), 8 nets.

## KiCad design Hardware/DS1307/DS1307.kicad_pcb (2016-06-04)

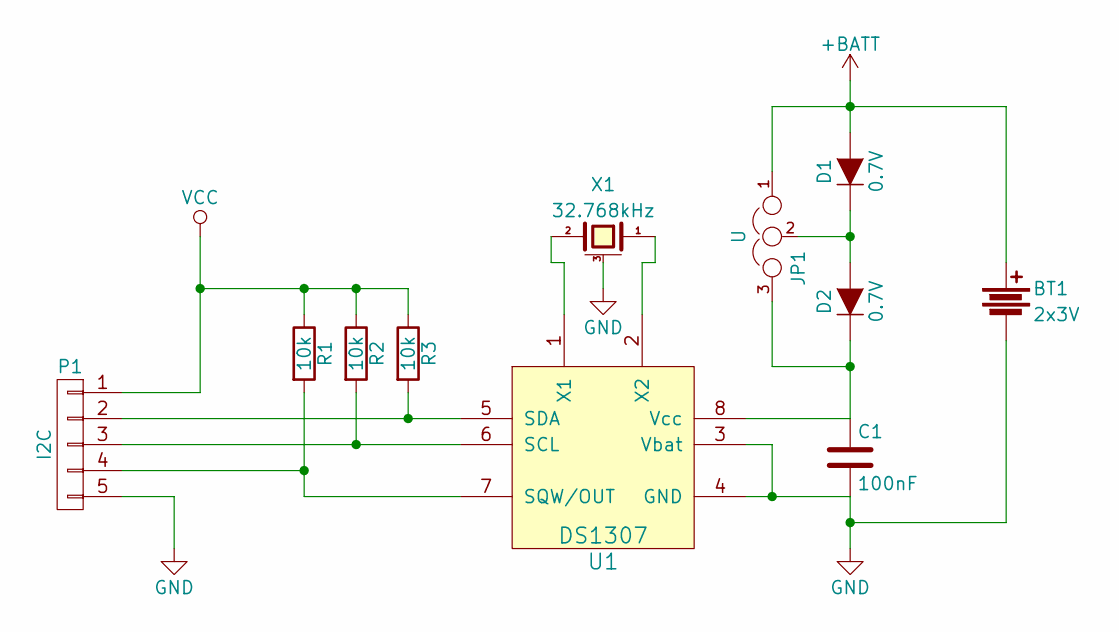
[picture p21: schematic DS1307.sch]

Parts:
BT1: 2x3V; KZH-20
C1: 100nF; C_0805_HandSoldering
D1, D2: 0.7V; R_1206_HandSoldering
JP1: U; SJ_2
P1: I2C; SMD_05-4mm
R1, R2, R3: 10k; R_0805_HandSoldering
U1: DS1307; SOIC-8_3.9x4.9mm_Pitch1.27mm
X1: 32.768kHz; MS1V-T1K

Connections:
+BATT: BT1.1, D1.2 (A), JP1.1
GND: BT1.2, C1.2, P1.5, U1.3 (Vbat), U1.4 (GND), X1.3 (case)
unnamed: C1.1, D2.1 (K), JP1.3, U1.8 (Vcc)
unnamed: D1.1 (K), D2.2 (A), JP1.2
unnamed: P1.2, R3.2, U1.5 (SDA)
unnamed: P1.3, R2.2, U1.6 (SCL)
unnamed: P1.4, R1.2, U1.7 (SQW/OUT)
unnamed: U1.1 (X1), X1.2
unnamed: U1.2 (X2), X1.1
VCC: P1.1, R1.1, R2.1, R3.1

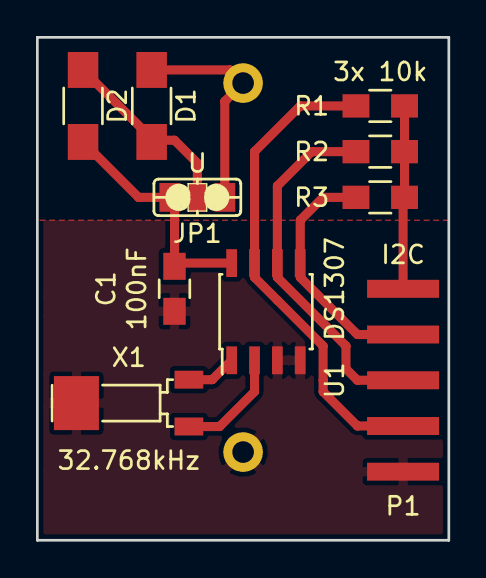
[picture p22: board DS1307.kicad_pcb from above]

Board: 2 copper layers, 22.9 x 27.9 mm, 11 parts (1 on the bottom side), 10 nets.

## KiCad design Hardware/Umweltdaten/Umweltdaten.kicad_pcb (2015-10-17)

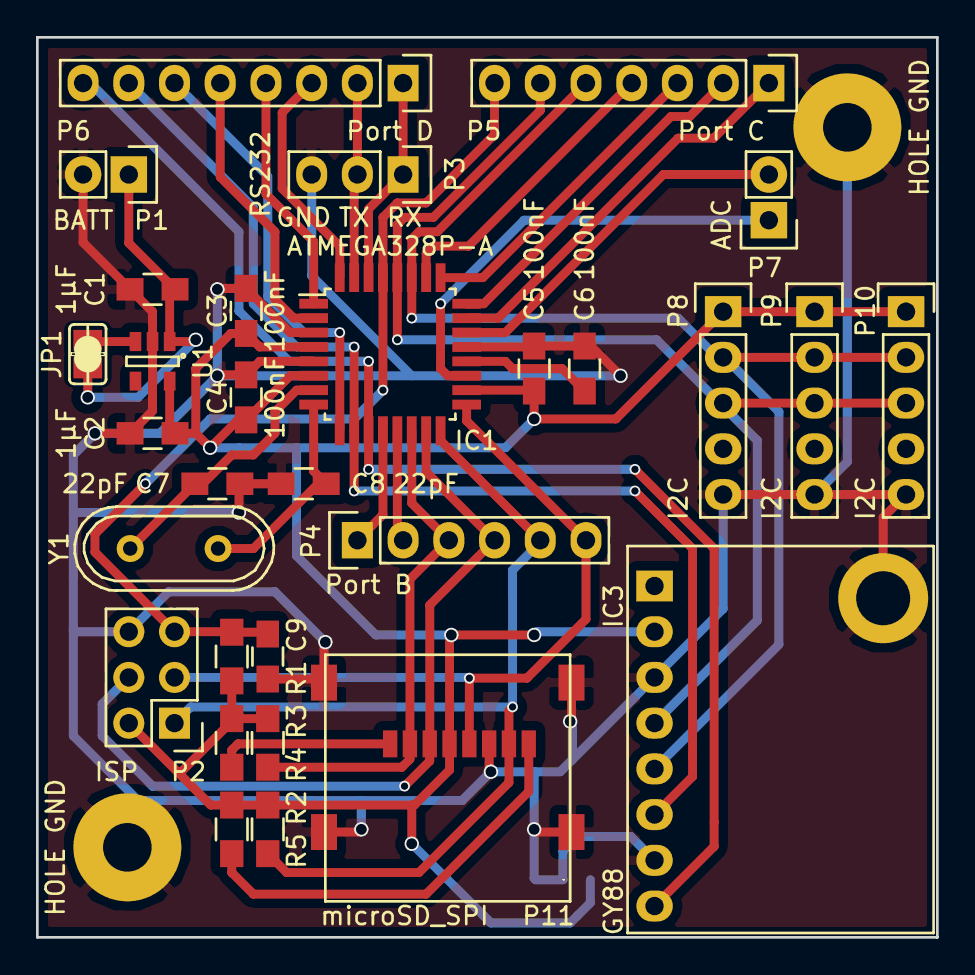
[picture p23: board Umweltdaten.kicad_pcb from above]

Board: 2 copper layers, 50.0 x 50.0 mm, 33 parts (1 on the bottom side), 31 nets.

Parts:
C1, C2: 1µF; C_0805_HandSoldering
C3, C4, C5, C6, C9: 100nF; C_0805_HandSoldering
C7, C8: 22pF; C_0805_HandSoldering
HOLE GND: MountingHole_2-7mm
HOLE GND#2: MountingHole_2-7mm
IC1: ATMEGA328P-A; TQFP-32_7x7mm_Pitch0.8mm
IC3: GY88
JP1: Ureg EN; SJ
JP2: G_AD0; SJ_2
P1: BATT; Pin_Header_Straight_1x02
P2: ISP; Pin_Header_Straight_2x03
P3: RS232; Pin_Header_Straight_1x03
P4: Port B; Pin_Header_Straight_1x06
P5: Port C; Pin_Header_Straight_1x07
P6: Port D; Pin_Header_Straight_1x08
P7: ADC; Pin_Header_Straight_1x02
P8, P9, P10: I2C; Pin_Header_Straight_1x05
P11: microSD_SPI; microSD
R1, R2, R3, R4, R5: 10k; R_0805_HandSoldering
U1: TLV70233DBV; SOT-23-5
Y1: Crystal 16Mhz; Crystal_HC49-U_Vertical

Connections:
+3V3: C2.1, C3.1, C4.1, C5.1, IC1.4, IC1.6, IC1.18, IC3.2, JP2.1, P2.2, P8.1, P9.1, P10.1, P11.4, R1.1, R2.1, R3.1, R4.1, R5.1, U1.5
+BATT: C1.1, JP1.1, JP1.2, P1.1, U1.1, U1.3
ADC6: IC1.19, P7.1
ADC7: IC1.22, P7.2
GND: C1.2, C2.2, C3.2, C4.2, C5.2, C6.2, C7.2, C8.2, C9.2, HOLE GND.1, HOLE GND#2.1, IC1.3, IC1.5, IC1.21, IC3.3, IC3.7, JP2.2, JP2.3, P1.2, P2.6, P3.3, P8.5, P9.5, P10.5, P11.6, P11.9, P11.10, P11.11, P11.12, U1.2
MISO: IC1.16, P2.1, P4.5, P11.7, R2.2
unnamed: C6.1, IC1.20
unnamed: P11.1, R4.2
unnamed: P11.8, R5.2
PB0: IC1.12, P4.1
PB1: IC1.13, P4.2
PB2: IC1.14, P4.3, P11.2, R3.2
PB3: IC1.15, P2.4, P4.4, P11.3
PB6: C7.1, IC1.7, Y1.1
PC0: IC1.23, P5.1
PC1: IC1.24, P5.2
PC2: IC1.25, P5.3
PC3: IC1.26, P5.4
PC6: C9.1, IC1.29, P2.5, P5.7, R1.2
PD0: IC1.30, P3.1, P6.1
PD2: IC1.32, P6.3
PD3: IC1.1, P6.4
PD4: IC1.2, P6.5
PD5: IC1.9, P6.6
PD6: IC1.10, IC3.6, P6.7
PD7: IC1.11, IC3.8, P6.8
SCK: IC1.17, P2.3, P4.6, P11.5
SCL: IC1.28, IC3.4, P5.6, P8.3, P9.3, P10.3
SDA: IC1.27, IC3.5, P5.5, P8.2, P9.2, P10.2
TX: IC1.31, P3.2, P6.2
XTAL2: C8.1, IC1.8, Y1.2

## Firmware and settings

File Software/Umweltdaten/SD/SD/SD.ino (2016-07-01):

#include <SPI.h>
#include <SD.h>
#include <Wire.h>
#include <DHT.h>

#define tmp75_address_1 0x48
#define bmp085_address 0x77
#define ds1307_address 0x68

#define DHTPIN 8
#define DHTTYPE DHT22

unsigned long previousMillis = 0;
const long interval = 1000;

File file;
DHT dht(DHTPIN, DHTTYPE);

const int CS = 10;  //SPI chip select for SDcard
const int batteryPin = A7;  //ADC pin to messure battery voltage

const unsigned char OSS = 0;  //Oversampling Setting for BMP085

//-----BMP085-----
// Calibration values
int ac1;
int ac2;
int ac3;
unsigned int ac4;
unsigned int ac5;
unsigned int ac6;
int b1;
int b2;
int mb;
int mc;
int md;

// b5 is calculated in bmp085GetTemperature(...), this variable is also used in bmp085GetPressure(...)
// so ...Temperature(...) must be called before ...Pressure(...).
long b5;
//-----end BMP085-----


void setup()
{
  Serial.begin(9600);
  Serial.println("Serial start");

  analogReference(INTERNAL);
  pinMode(batteryPin, INPUT);
  Serial.println("ADC start");

  dht.begin();
  Serial.println("DHT22 start");

  Wire.begin();
  Serial.println("Wire start");

  if (SD.begin(CS))
  {
    Serial.println("SD start");
  }
  else
  {
    Serial.println("SD start failed");
  }

  file = SD.open("test.txt", FILE_WRITE);
  if (file)
  {
    Serial.println("File open");
  }
  else
  {
    Serial.println("File open failed");
  }

  Wire.beginTransmission(tmp75_address_1);    //write to TMP75
  Wire.write(0x1);                            //set pointer register: 01 = configuration
  Wire.write(0x61);                           //write configuration
  Wire.endTransmission();
  Serial.println("TMP75 start");

  bmp085Calibration();
  Serial.println("BMP085 start");

  Serial.print("temperature 1;");
  Serial.print("temperature 2;");
  Serial.print("temperature 3;");
  Serial.print("humidity;");
  Serial.print("pressure;");
  Serial.print("atm;");
  Serial.print("altitude;");
  Serial.print("battery;");
  Serial.print("time;");
  Serial.println("n");

  file.print("temperature 1;");
  file.print("temperature 2;");
  file.print("temperature 3;");
  file.print("humidity;");
  file.print("pressure;");
  file.print("atm;");
  file.print("altitude;");
  file.print("battery;");
  file.print("time;");
  file.println("n");
}

void loop()
{
  int n = 0;
  byte time[7];

  while (n < 60)
  {
    unsigned long currentMillis = millis();

    if (currentMillis - previousMillis >= interval)
    {
      previousMillis = currentMillis;
      n++;

      ds1307(ds1307_address, time);

      float temperature_3 = tmp75(tmp75_address_1);

      float humidity = dht.readHumidity();
      float temperature_2 = dht.readTemperature();

      float temperature_1 = bmp085GetTemperature(bmp085ReadUT()); //MUST be called first
      float pressure = bmp085GetPressure(bmp085ReadUP());
      float atm = pressure / 101325; // "standard atmosphere"
      float altitude = calcAltitude(pressure); //Uncompensated caculation - in Meters

      int battery = analogRead(batteryPin);

      Serial.print(temperature_1, 1);
      Serial.print(";");
      Serial.print(temperature_2, 1);
      Serial.print(";");
      Serial.print(temperature_3, 4);
      Serial.print(";");

      Serial.print(humidity, 1);
      Serial.print(";");

      Serial.print(pressure, 0);
      Serial.print(";");
      Serial.print(atm, 4);
      Serial.print(";");
      Serial.print(altitude, 2);
      Serial.print(";");

      Serial.print(battery);
      Serial.print(";");

      Serial.print(time[6], HEX);
      Serial.print("-");
      Serial.print(time[5], HEX);
      Serial.print("-");
      Serial.print(time[4], HEX);
      Serial.print("T");
      Serial.print(time[2], HEX);
      Serial.print(":");
      Serial.print(time[1], HEX);
      Serial.print(":");
      Serial.print(time[0], HEX);
      Serial.print(";");

      Serial.println(n);


      file.print(temperature_1, 1);
      file.print(";");
      file.print(temperature_2, 1);
      file.print(";");
      file.print(temperature_3, 4);
      file.print(";");

      file.print(humidity, 1);
      file.print(";");

      file.print(pressure, 0);
      file.print(";");
      file.print(atm, 4);
      file.print(";");
      file.print(altitude, 2);
      file.print(";");

      file.print(battery);
      file.print(";");

      file.print(time[6], HEX);
      file.print("-");
      file.print(time[5], HEX);
      file.print("-");
      file.print(time[4], HEX);
      file.print("T");
      file.print(time[2], HEX);
      file.print(":");
      file.print(time[1], HEX);
      file.print(":");
      file.print(time[0], HEX);
      file.print(";");

      file.println(n);

    }
  }
  file.flush();
  Serial.println("save");
}

void ds1307(byte address, byte* time)
{
  Wire.beginTransmission(address);    //write to DS1307
  Wire.write(0x0);                    //set  pointer register
  Wire.endTransmission(false);        //Start repeat

  Wire.requestFrom(address, 7);       //read from DS1307: seconds - year
  if (Wire.available())
  {
    time[0] = Wire.read();            //second
    time[1] = Wire.read();            //minute
    time[2] = Wire.read();            //hour
    time[3] = Wire.read();            //weekday
    time[4] = Wire.read();            //date
    time[5] = Wire.read();            //month
    time[6] = Wire.read();            //year
  }
}

float tmp75(byte address)
{
  byte msb;
  byte lsb;
  word data;
  float shift;
  float temperature;

  Wire.beginTransmission(address);   //write to TMP75
  Wire.write(0x1);                    //set pointer register: 01 = configuration
  Wire.write(0xE1);                    //write configuration: One-Shot
  Wire.endTransmission();

  Wire.beginTransmission(address);    //write to TMP75
  Wire.write(0x0);                    //set pointer register: 00 = temperature
  Wire.endTransmission(false);        //end write to TMP75

  Wire.requestFrom(address, 2);       //read register(temperature)
  if (Wire.available())
  {
    msb = Wire.read();                //first byte(T11 - T4)
    lsb = Wire.read();                //second byte(T3 - T0, first four bits always 0)
  }

  data = word(msb, lsb);              //put first and second byte together
  shift = data >> 4;                  //bitshift >> 4: removes the four zeros in the second byte
  temperature = shift / 16;           //calculates the temperature

  return temperature;                 //returns the temperature
}

//-----BMP085-----
// Stores all of the bmp085's calibration values into global variables
// Calibration values are required to calculate temp and pressure
// This function should be called at the beginning of the program
void bmp085Calibration()
{
  ac1 = bmp085ReadInt(0xAA);
  ac2 = bmp085ReadInt(0xAC);
  ac3 = bmp085ReadInt(0xAE);
  ac4 = bmp085ReadInt(0xB0);
  ac5 = bmp085ReadInt(0xB2);
  ac6 = bmp085ReadInt(0xB4);
  b1 = bmp085ReadInt(0xB6);
  b2 = bmp085ReadInt(0xB8);
  mb = bmp085ReadInt(0xBA);
  mc = bmp085ReadInt(0xBC);
  md = bmp085ReadInt(0xBE);
}

// Calculate temperature in deg C
float bmp085GetTemperature(unsigned int ut) {
  long x1, x2;

  x1 = (((long)ut - (long)ac6) * (long)ac5) >> 15;
  x2 = ((long)mc << 11) / (x1 + md);
  b5 = x1 + x2;

  float temp = ((b5 + 8) >> 4);
  temp = temp / 10;

  return temp;
}

// Calculate pressure given up
// calibration values must be known
// b5 is also required so bmp085GetTemperature(...) must be called first.
// Value returned will be pressure in units of Pa.
long bmp085GetPressure(unsigned long up) {
  long x1, x2, x3, b3, b6, p;
  unsigned long b4, b7;

  b6 = b5 - 4000;
  // Calculate B3
  x1 = (b2 * (b6 * b6) >> 12) >> 11;
  x2 = (ac2 * b6) >> 11;
  x3 = x1 + x2;
  b3 = (((((long)ac1) * 4 + x3) << OSS) + 2) >> 2;

  // Calculate B4
  x1 = (ac3 * b6) >> 13;
  x2 = (b1 * ((b6 * b6) >> 12)) >> 16;
  x3 = ((x1 + x2) + 2) >> 2;
  b4 = (ac4 * (unsigned long)(x3 + 32768)) >> 15;

  b7 = ((unsigned long)(up - b3) * (50000 >> OSS));
  if (b7 < 0x80000000)
    p = (b7 << 1) / b4;
  else
    p = (b7 / b4) << 1;

  x1 = (p >> 8) * (p >> 8);
  x1 = (x1 * 3038) >> 16;
  x2 = (-7357 * p) >> 16;
  p += (x1 + x2 + 3791) >> 4;

  long temp = p;
  return temp;
}

// Read 1 byte from the BMP085 at 'address'
char bmp085Read(unsigned char address)
{
  unsigned char data;

  Wire.beginTransmission(bmp085_address);
  Wire.write(address);
  Wire.endTransmission();

  Wire.requestFrom(bmp085_address, 1);
  if (Wire.available())
  {
    data = Wire.read();
  }

  return data;
}

// Read 2 bytes from the BMP085
// First byte will be from 'address'
// Second byte will be from 'address'+1
int bmp085ReadInt(unsigned char address)
{
  unsigned char msb, lsb;

  Wire.beginTransmission(bmp085_address);
  Wire.write(address);
  Wire.endTransmission();

  Wire.requestFrom(bmp085_address, 2);
  if (Wire.available() >= 2)
  {
    msb = Wire.read();
    lsb = Wire.read();
  }
  return (int) msb << 8 | lsb;
}

// Read the uncompensated temperature value
unsigned int bmp085ReadUT() {
  unsigned int ut;

  // Write 0x2E into Register 0xF4
  // This requests a temperature reading
  Wire.beginTransmission(bmp085_address);
  Wire.write(0xF4);
  Wire.write(0x2E);
  Wire.endTransmission();

  // Wait at least 4.5ms
  delay(5);

  // Read two bytes from registers 0xF6 and 0xF7
  ut = bmp085ReadInt(0xF6);
  return ut;
}

// Read the uncompensated pressure value
unsigned long bmp085ReadUP() {

  unsigned char msb, lsb, xlsb;
  unsigned long up = 0;

  // Write 0x34+(OSS<<6) into register 0xF4
  // Request a pressure reading w/ oversampling setting
  Wire.beginTransmission(bmp085_address);
  Wire.write(0xF4);
  Wire.write(0x34 + (OSS << 6));
  Wire.endTransmission();

  // Wait for conversion, delay time dependent on OSS
  delay(2 + (3 << OSS));

  // Read register 0xF6 (MSB), 0xF7 (LSB), and 0xF8 (XLSB)
  msb = bmp085Read(0xF6);
  lsb = bmp085Read(0xF7);
  xlsb = bmp085Read(0xF8);

  up = (((unsigned long) msb << 16) | ((unsigned long) lsb << 8) | (unsigned long) xlsb) >> (8 - OSS);

  return up;
}

void writeRegister(int deviceAddress, byte address, byte val) {
  Wire.beginTransmission(deviceAddress); // start transmission to device
  Wire.write(address);       // send register address
  Wire.write(val);         // send value to write
  Wire.endTransmission();     // end transmission
}

int readRegister(int deviceAddress, byte address) {

  int v;
  Wire.beginTransmission(deviceAddress);
  Wire.write(address); // register to read
  Wire.endTransmission();

  Wire.requestFrom(deviceAddress, 1); // read a byte
  if (Wire.available())
  {
    v = Wire.read();
  }

  return v;
}

float calcAltitude(float pressure) {

  float A = pressure / 101325;
  float B = 1 / 5.25588;
  float C = pow(A, B);
  C = 1 - C;
  C = C / 0.0000225577;

  return C;
}

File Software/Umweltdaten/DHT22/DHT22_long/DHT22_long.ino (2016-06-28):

#include "DHT.h"

#define DHTPIN 2     // what digital pin we're connected to

#define DHTTYPE DHT22   // DHT 22  (AM2302), AM2321

DHT dht(DHTPIN, DHTTYPE);

void setup()
{
  Serial.begin(9600);
  dht.begin();
  Serial.println("DHT22 start"); 
}

void loop()
{
  float h = dht.readHumidity();
  float t = dht.readTemperature();

  Serial.print("humidity:");
  Serial.print(h,1);
  Serial.print("temperature:");
  Serial.println(t,1);
  
  delay(100);
}

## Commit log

2015-06-05 Update sstv.sh
    Wir haben was zu tun!
2015-06-06 Kopie von Rufzeichen und Testbild
2015-06-21 GY88 3.3V Umbau Schaltplan
2015-06-28 GY88 3.3V Umbau Layout
2015-08-18 add Umweltdaten schema
    [Umweltdaten.kicad_pcb, Umweltdaten.sch, atmega328.sch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]
2015-08-19 add some things
    [Umweltdaten.sch, atmega328.sch, con.sch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]
2015-08-19 add some things and fix ERC errors
    [atmega328.sch, con.sch, gy88.sch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]
2015-08-20 add footprint assignment
    [atmega328.sch, con.sch, gy88.sch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]
2015-08-20 routing PCB
    [atmega328.sch, con.sch]
2015-08-21 finish schema and PCB
    [Umweltdaten.kicad_pcb, Umweltdaten.sch, atmega328.sch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]
2015-08-22 add silkscreen and fix DRC errors
    [Umweltdaten.kicad_pcb]
2015-08-22 add gerber files
    [Umweltdaten-B_Cu.gbr, Umweltdaten-B_Mask.gbr, Umweltdaten-B_SilkS.gbr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]
2015-09-20 add logos and bom
    [Umweltdaten.csv, Umweltdaten.kicad_pcb]
2015-09-20 add LM/TMP75 PCB
    [LM75.kicad_pcb, LM75.sch, lm75.sch]
2015-10-17 Platine V2-final
    [Umweltdaten-B_Cu.gbl, Umweltdaten-B_Mask.gbs, Umweltdaten-B_SilkS.gbo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]
2015-11-06 files changed while ordering the pcb
2015-11-06 TMP75 arduino sketch added
2015-11-06 BMP085 arduino sketch added
2015-11-06 Revert "BMP085 arduino sketch added"
    This reverts commit c30323349d64004dd2e94f92d630d01dd3fd3dc9.
    [BMP085.ino]
2015-11-06 Revert "Revert "BMP085 arduino sketch added""
    This reverts commit 1e19f4affd4d484d9b8227db6644ecbaaca4d60d.
    [BMP085.ino]
2015-11-06 make some wrong things back
    [BMP085.ino]
2015-11-06 BMP085 and TMP75 arduino sketch added
2016-04-19 Update Umweltdaten
    [LM75.kicad_pcb, LM75.sch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]
2016-04-24 change variables from int to float to enable higher temperature resulution
2016-04-24 Revert "Update Umweltdaten"
    This reverts commit 07671d206f2da155dbf86959c01b7aa278c26477.
    [LM75.kicad_pcb, LM75.sch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]
2016-05-15 LM/TMP75 layout
    [LM75.kicad_pcb, LM75.sch]
2016-05-16 finished LM/TMP75 PCB
    [LM75.kicad_pcb, LM75.sch]
2016-05-29 RTC DS1307 schematic and layout
    [DS1307_3V3.kicad_pcb, DS1307_3V3.sch]
2016-06-04 work on layout
    [DS1307_3V3.kicad_pcb, DS1307_3V3.sch]
2016-06-04 finished DS1307 and renamed it
    [DS1307.kicad_pcb, DS1307.sch, DS1307_3V3.kicad_pcb]
2016-06-05 create Gerber files
    [DS1307-B_Cu.gbl, DS1307-B_Mask.gbs, DS1307-B_SilkS.gbo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]
2016-06-28 add battery voltage
2016-06-30 fix issue with endless loop when BMP085 not available
    [BMP085.ino]
2016-07-01 fix from commit b65cb30
    [SD.ino]
2016-07-02 Preperation for impementation DHT22
    send Data from DHT22 via SSTV to ground
2016-07-26 Umweltdaten Auswertung
    [Umweltdaten-Tabelle.ods, Umweltdaten-Tabelle.xls]
